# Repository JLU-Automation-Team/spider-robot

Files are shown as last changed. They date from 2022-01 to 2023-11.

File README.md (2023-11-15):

# 基于树莓派的六足机器人方案设计
## 工程内容说明
### hardware为项目相关硬件设计

 * 机械结构为六足机器人的3d建模工程，包括本体和云台<br>
 *  遥控器在ESP32最小开发板上集成了MPU6050和OLED接口并设计了使能引脚，可以选择是否收发外设数据
<br>文件包括PCB的立创EDA文件、Altium文件与3d模型<br>
### code文件夹内为使用到的各种代码

 * 包括pc控制的上位机和图传程序及其服务器程序、体感遥控器的驱动程序和树莓派部分执行程序
 * 遥控器代码和说明来自stratosphericus(Github)
### resource文件夹为项目相关的资料

 * 包括舵机控制板的串口控制指令说明以及运动控制理论及相关资料
 * 详细运控资料来自Panzer-Crow(Github)整理
### software为使用到的软件内容

 * 舵机控制板的图形化编程上位机以及可能使用到的串口驱动
## 简单预览

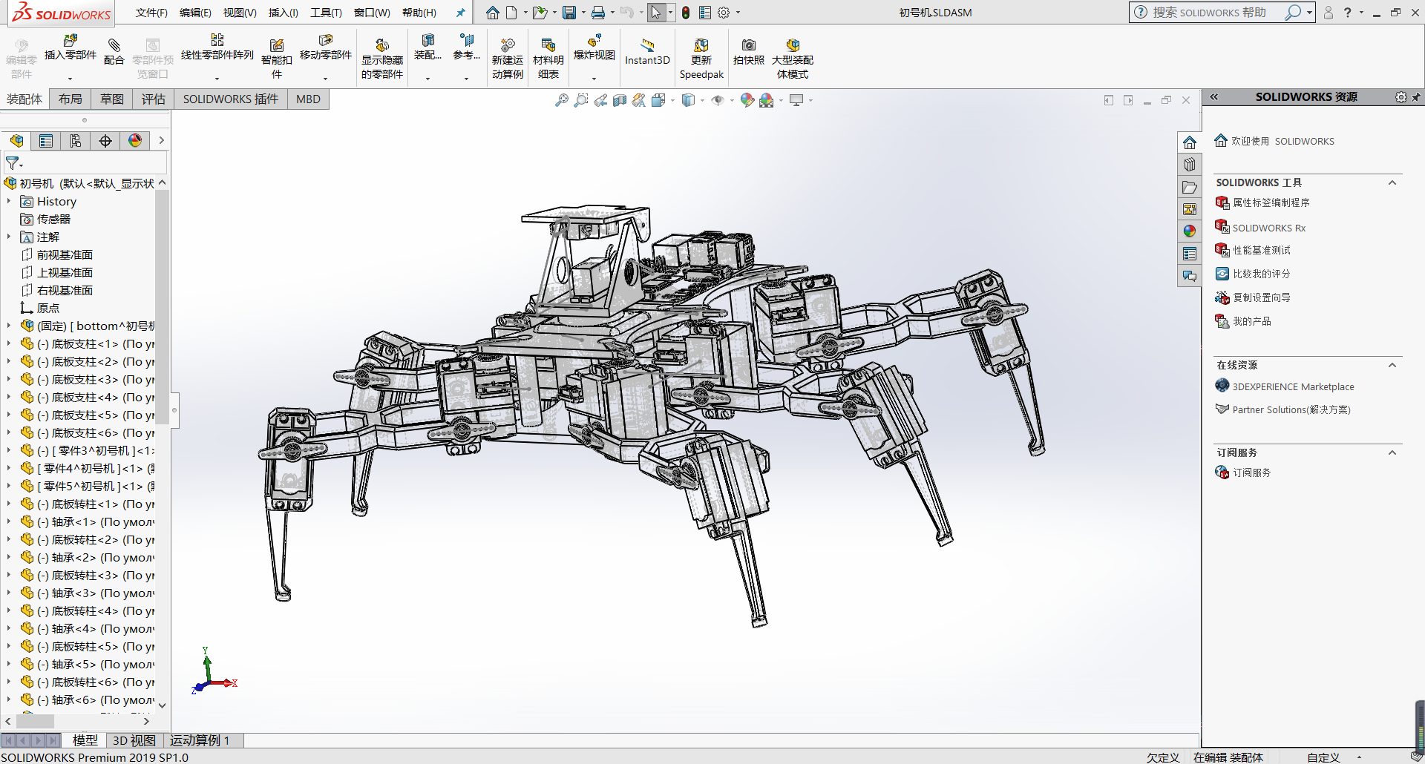
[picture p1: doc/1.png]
<br>
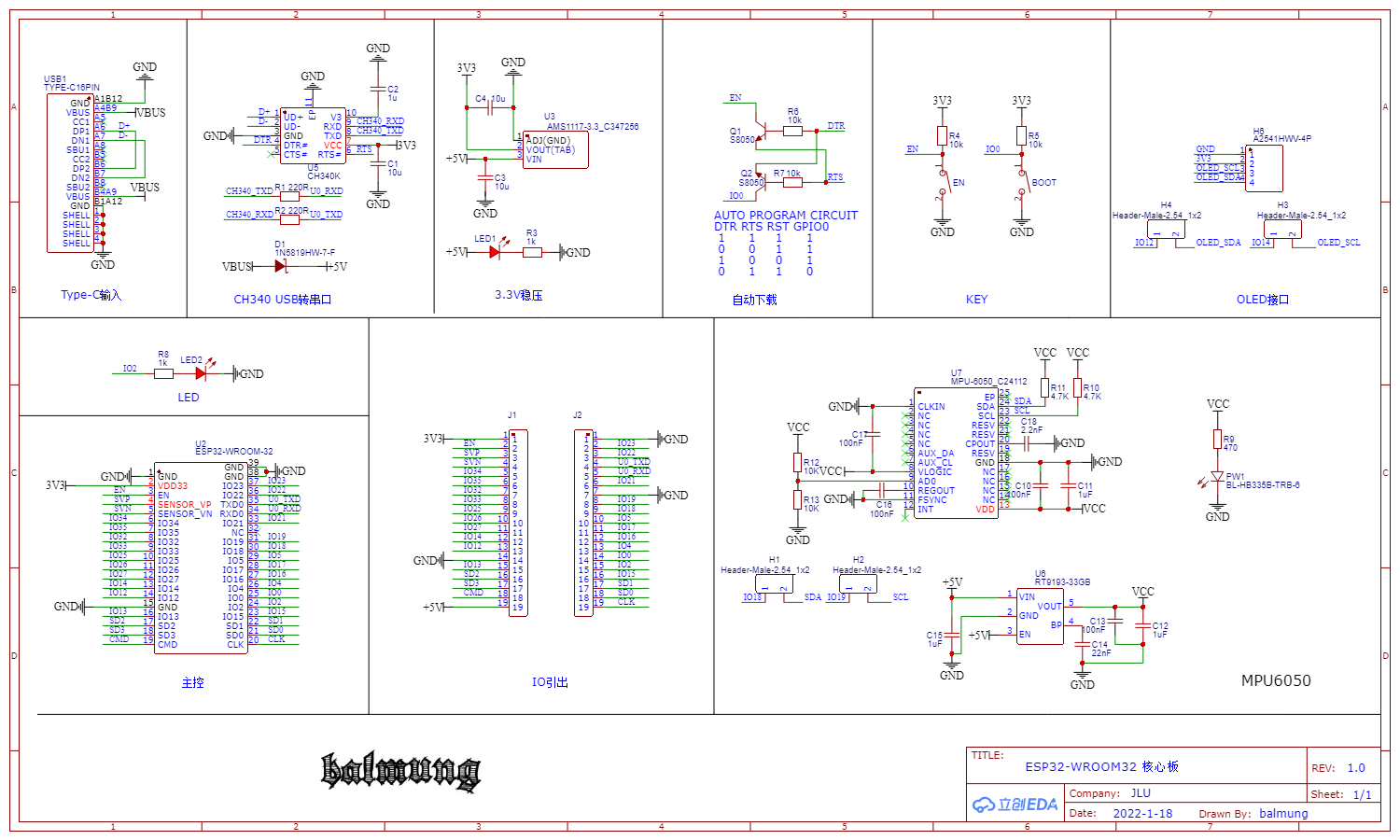
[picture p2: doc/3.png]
<br>
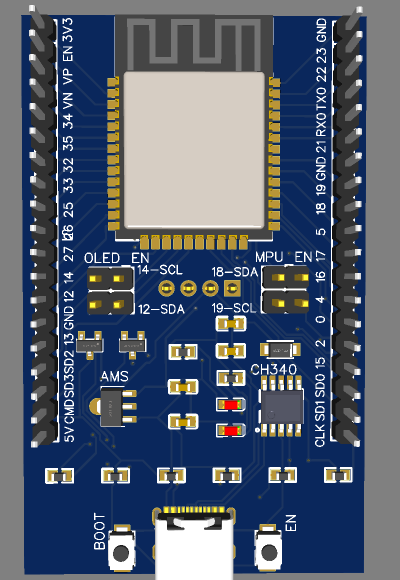
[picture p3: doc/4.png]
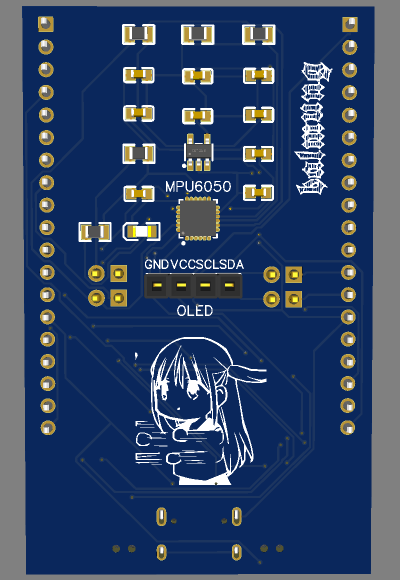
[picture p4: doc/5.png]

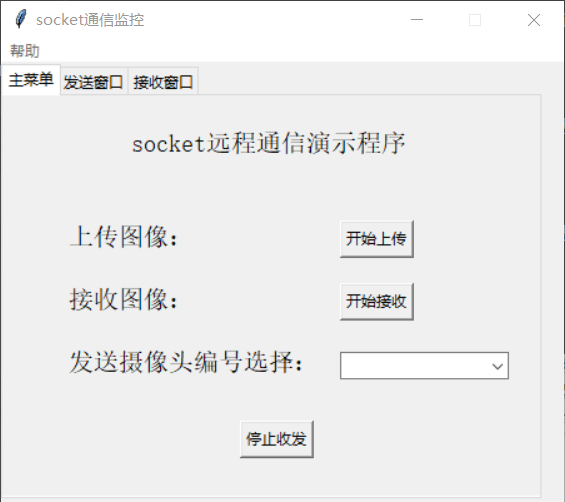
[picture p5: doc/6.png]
!<br>

## 参考与致谢

> 本说明来自balmung08(Github)<br>
> 此项目在设计中参考了https://grabcad.com/library/spider-robot-v2-0-mg995-servo-quadruped-on-stm32f103-1
感谢这帮俄国佬<br>
另外，立创EDA永远的神，我认为大家都应该试一试.jpg

>因为马上就要考研了，我们没有时间将设计做成实物，但是在设计过程中仍旧有很大收获<br>
感谢愿意陪着我一起抽风做这玩意的两位队友: BH3GEI,Panzer-Crow

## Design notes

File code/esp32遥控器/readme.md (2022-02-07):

# 基于esp32的体感手势遥控器
## 程序基本思路
### mpu6050数据处理
 * 从水平静置调零后的传感器获取三轴线加速度数据和三轴角加速度数据
 * 利用三轴线加速度数据和当地重力加速度计算出左右前后相对水平面的倾角
 * 利用z轴角速度计得到水平旋转角速度
 * 根据传感器数值分级输出移动指令和转向指令

### oled屏幕显示
 * 前两行内容分别是指令信息、局域网ip地址

### webserver的简单实现
 * 定义好响应头之后进入死循环开始监听，响应来自客户端的GET请求
 * 返回内容是一个与oled屏幕第一行内容相同的字符串

## 食用方法
 * 接好供电，连好引脚（mpu和oled都是3v3供电；mpu的接gpio5, sda接gpio4；oled的sda接gpio13, scl接gpio14）
 * 晃动遥控器
 * 树莓派的运控程序向esp32的ip地址(80端口)发送GET请求，得到遥控器产生的指令(同时指令会在oled上显示)

## 可能存在的问题
 * oled与mpu6050直接并联在esp32的3v3和gnd管脚之间可能导致mpu6050烧毁

## 参考来源：

>mpu6050的驱动来源: https://github.com/macalencar/micropython-mpu6050/blob/main/mpu6050.py

>ssd1306 oled屏幕的驱动来源: https://github.com/adafruit/micropython-adafruit-ssd1306/blob/master/ssd1306.py

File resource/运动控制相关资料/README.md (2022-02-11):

* 本部分说明文档涉及大量公式，Github无法正常加载，请下载项目后使用markdown阅读器打开

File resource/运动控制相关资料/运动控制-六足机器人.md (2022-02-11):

# 运动控制方案
## 实例项目——六足机器人（Spider Robot）
 
------
### 写在方案前的话
**本方案根据<font color=#dd0000>严密数学建模</font>和<font color=#dd0000>工程快速实现</font>的方面不同准备有两套不同操作方案，希望了解严密数学建模的朋友请耐心看完全文，有迫切工程实现需求的朋友可在看完第1点简介后直接，从第五点开始查看，需要说明的是，两种方式仅在学习的时间成本上会有明显不同，在具体项目实现的时间上会因为个人的熟练程度的因素不一定会展现出差异**

### 目录
> * 1.本项目六足机器人简介
> * 2.常用机械臂模型——DH模型的基本思想
> * 3.DH模型提出的数学原理
> * 4.本项目六足机器人的单足（单机械臂）建模方式
> * 5.本项目六足机器人的多足（多机械臂）运动逻辑——步态规划
> * 6.项目工程实现方式及相关软件
> * 7.注意要点

------
### 1.本项目六足机器人简介
项目SolidWorks预览图
 **项目SolidWorks预览图**

 在运动控制方面，本项目六足机器人使用树莓派作为主控板，使用24路舵机控制板作为18个舵机（6足：每足3个）的运动控制，并且使用降压芯片将7.4V电池电压降为6.2V电压给舵机控制板供电；在舵机选用上，使用最为常见的MG995舵机，并使用Lobot Servo Control软件对18个舵机同一管理。

------
### 2.常用机械臂模型——DH模型的基本思想
DH模型，即Denavit-Hartenberg模型，是连杆结构常用的建模方式，可以运用于任何机器人的运动构型，特别是在多自由度机械臂上运用广泛。

在DH模型中，一个多自由度的连杆结构（或机械臂）是由一个个<font color=#dd0000>关节</font>和<font color=#dd0000>连杆</font>组成的，其中每个关节只有一个自由度，根据运动形式的不同，关节可分为滑动关节（P关节）和转动关节（R关节）。

这里我们引入两个概念：<font color=#dddd00>正运动学</font>和<font color=#dddd00>逆运动学</font>，<font color=#dddd00>正运动学</font>即是指已知各个关节的运动参数，求末端执行器相对于参考坐标的位姿,<font color=#dddd00>逆运动学</font>是指根据已给定的满足工作要求的末端执行器相对于末端执行器的位置和姿态，求各个关节的运动参数。以正运动学为背景的话，DH模型通过限制**原点位置**和**X轴方向**，可以人为的减少2个参数，所以只需要4个参数就可以表达关节之间原本6参数才能表达的坐标变换。

------
### 3.DH模型提出的数学原理
* DH模型的四个核心参数
  
> * 连杆长度（link length）：两个关节之间公共法线长度，以符号a<sub>i−1</sub> 表示,
> 【对于关节点O<sub>i-1</sub> 和 O<sub>i</sub> 】
> * 连杆扭转（link twist）： 一个关节的轴相对于另一个关节的轴绕他们公共法线的旋转角度,以符号α<sub>i−1</sub>表示 
> 【对于关节点O<sub>i-1</sub> 和 O<sub>i</sub> 】
> * 连杆偏移（link offset）：一个关节余下一个关节的公共法线和这个关节与它上一个关节公共法线沿这个关节轴的距离，以符号d<sub>i </sub>表示
> 【对于轴X<sub>i-1</sub> 和 X<sub>i</sub> 】
> * 关节转角（joint angel）：一个关节与下一个关节公共法线和它与上一个关节的公共法线绕这个关节的转角，以符号θ<sub>i</sub> 表示
> 【对于轴X<sub>i-1</sub> 和 X<sub>i</sub> 】

* 模型图像

------
<center>
    
</center>

<center>

**任意一个拥有三个关节和两根连杆的机械结构【真实视图】**

</center>

<center class="half">
    
</center>

$~~~~~~~~~~~~~~~~~$**抽象数学模型视图【正视图】**$~~~~~~~~~~~~~~~~~~~~~~~~~~~~~~~~~~~~~~~~~~~~~$**抽象数学模型视图【左视图】**

<center class="half">
    
</center>

$~~~~~~~~~~~~~~~~~$**抽象数学模型视图【正视图】**  $~~~~~~~~~~~~~~~~~$$~~~~~~~~~~~~~~~~~$$~~~~~~~~~~~$**抽象数学模型视图【正视图】**

$~~~~~~~~~~~~~~~~~$**（去掉1，3号关节转轴）**$~~~~~~~~~~~~~~~~~$$~~~~~~~~~~~~~~~~~$$~~~~~~~~~~~~~~~~~$**（去掉1，3号关节转轴）**

------
* 矩阵计算——涉及空间坐标变换

$$
空间坐标变换
\left\{ 
\begin{matrix}
二维图形变换【旧坐标(x,y)——>新坐标(X,Y)】
\left\{ 
\begin{matrix}
平移 \\
缩放（此处不考虑）\\
旋转\\
\end{matrix}
\right. \\
三维图形变换【旧坐标(x,y,z)——>新坐标(X,Y,Z)】
\left\{ 
\begin{matrix}
平移 \\
缩放（此处不考虑）\\
旋转\\
\end{matrix}
\right.\\
\end{matrix}
\right.
$$

> 为方便计算，在这里我们引入齐次坐标，齐次坐标是一种标记方式
>* 对于二维坐标点来说，原来为（x,y）的坐标表示为（x,y,1）
>* 对于二维坐标点来说，原来为（x,y,z）的坐标表示为（x,y,z,1）
>* 齐次坐标可以在空间变换计算中区分向量和坐标，如二维的：
$$
\left\{ 
\begin{matrix}
向量：（x,y,0）\\
坐标： (x,y,1) \\
\end{matrix}
\right.
$$

$$
二维平移变换【引入齐次坐标后，等待变换的点：（x,y,1）】
\left\{ 
\begin{matrix}
变换公式
\left\{ 
\begin{matrix}
X=x+\delta x \\
Y=y+\delta y\\
\end{matrix}
\right.\\
变换矩阵:\left[
 \begin{matrix}
   1 & 0 & \delta x \\
   0 & 1 & \delta y \\
   0 & 0 & 1 
  \end{matrix}
  \right] *(x,y,1)=[x+\delta x,y+\delta y,1] \\
\end{matrix}
\right.
$$

$$
二维旋转变换【引入齐次坐标后，等待变换的点：（x,y,1）】
\left\{ 
\begin{matrix}
变换公式
\left\{ 
\begin{matrix}
X=x*cos\theta -y*sin\theta \\
Y=y*cos\theta +x*sin\theta \\
\end{matrix}
\right.\\
变换矩阵:\left[
 \begin{matrix}
   cos\theta & -sin\theta & 0 \\
   sin\theta & cos\theta & 0 \\
   0 & 0 & 1 
  \end{matrix}
  \right] *(x,y,1)=[x*cos\theta -y*sin\theta,y*cos\theta +x*sin\theta,1] \\
\end{matrix}
\right.
$$

> 推得各个变换矩阵（左乘坐标变换）：
> (证明为三角变换内容，此处省略)
> 二维平移变换矩阵：
$$
\left[
 \begin{matrix}
   1 & 0 & \delta x \\
   0 & 1 & \delta y \\
   0 & 0 & 1 
  \end{matrix}
  \right]
$$
> 二维旋转变换矩阵：
$$
\left[
 \begin{matrix}
   cos\theta & -sin\theta & 0 \\
   sin\theta & cos\theta & 0 \\
   0 & 0 & 1 
  \end{matrix}
  \right] 
$$

> 三维同理：
> 三维维平移变换矩阵：
$$
\left[
 \begin{matrix}
   1 & 0 & 0 &\delta x  \\
   0 & 1 & 0 & \delta y \\
   0 & 0 & 1 & \delta z \\
   0 & 0 & 0 &    1     \\
  \end{matrix}
  \right]
$$
> 三维旋转变换矩阵：
> 若绕X轴:
> $$
\left[
 \begin{matrix}
   cos\theta & -sin\theta &  0  &  0\\
   sin\theta & cos\theta  &  0  &  0\\
   0         &     0      &  1  &  0\\
   0         &     0      &  0  &  1
  \end{matrix}
  \right] 
$$
> 若绕Y轴:
> $$
\left[
 \begin{matrix}
   cos\theta & 0 &  -sin\theta  &  0\\
   0 &  1 &  0  &  0\\
   sin\theta   &     0     &  cos\theta  &  0\\
   0         &     0      &  0  &  1
  \end{matrix}
  \right] 
$$
> 若绕Z轴:
> $$
\left[
 \begin{matrix}
   1 & 0 &  0  &  0\\
   0 & cos\theta & -sin\theta &  0\\
   0         &     sin\theta & cos\theta  & 0\\
   0         &     0      &  0  &  1
  \end{matrix}
  \right] 
$$

对于我们研究的六足机器人项目（三维结构），根据每两个关节之间的的旋转变换矩阵（R<sub>x</sub>或R<sub>y</sub>或R<sub>z</sub>）和平移变换矩阵（T）相乘再与原坐标左乘，就可得到下一个点的坐标，递推直到获得末端足姿坐标。**这样一来，我们便实现了由已知各个关节的运动参数，求得末端执行器相对于参考坐标的位姿【由于推导比较麻烦，为回避计算量，下一板块会直接给出两关节间化简后的的变换矩阵，在填好DH表格后，可直接由数据计算坐标】**

------
### 4.本项目六足机器人的单足（单机械臂）建模方式——正运动学与逆运动学

-----

####正运动学分析

#### ①物理结构抽象
  
<center>

项目单臂机械结构示例图

 **项目单臂机械结构示例图**

</center>
#### ②数学抽象 

<center>

项目数学模型抽象示例图
 **项目数学模型抽象示例图**

</center>

* 对于一个机械臂的每一个关节 指定一个本地参考坐标系，即指定一个<font color=#dd0000>X轴</font>和一个<font color=#dd0000>Z轴</font>：其中Z轴以右手螺旋定则按照旋转方向规定正方向，X轴分两种情况：若两关节轴不平行或相交，用最短公垂线为X轴；平行，用无数条相等的公垂线中任选一条为X轴

#### ③明确参数，填写DH表格

| i | a<sub>i−1  | α<sub>i−1 |d<sub>i |θ<sub>i  |
| ---| :-----:  | :----:  |:----:|:----:|
| 1 | | | | |
| 2 | | | | |
| 3 | | | | |

#### ④将表格数据代入两关节间化简后转换矩阵公式
> $$
T_{i-1}=
 \left[
 \begin{matrix}
   cos\theta _i & -sin\theta _i & 0 & \ a_{i-1} \\
   sin\theta _icos\alpha _{i-1} & cos\theta _icos\alpha _{i-1} & -sin\alpha _{i-1}&-sin\alpha _{i-1}d_i\\
  sin\alpha _{i-1}sin\theta _i & cos\theta _isin\alpha _{i-1} & cos\alpha _{i-1} &cos\alpha _{i-1}d_i\\
   0 & 0 & 0 &1\\
  \end{matrix}
  \right] 
$$ 

#### ⑤将得到的变换矩阵T<sub>0</sub>、T<sub>1</sub>、T<sub>2</sub>与原始坐标（0,0,0,1）相乘得到足端位姿坐标：
> （X,Y,Z,1）=T<sub>2</sub>*T<sub>1</sub>*T<sub>0</sub> *(0,0,0,1)

------
#### 逆运动学分析
不同与正运动学清晰的矩阵计算，逆运动学的处理显得更为复杂，逆运动学的求解一般有**数值解计算**和**封闭形式解决方案**。由于本项目并非多自由度的工业机械臂一类的应用场景，可以通过之后描述的方案二使用**人为试错**的方式获得舵机转角值，在此不对逆运动学解做具体阐述，只是保证知识完整性做相关说明。
在实际运用中，我们并不是通过已知的各舵机转角来获得末端位姿。相反，我们需要在已知目标末端位姿（x,y,z,1）的前提下，获得每个舵机的转角以输入程序使得舵机带动机械臂末端到达目标位置。可以说，逆运动学在实际中的运用要多于正运动学。

具体的求解方法可参考CSDN博客：
网址链接：[尘埃落定123——《逆运动学》]([C:2.png](https://blog.csdn.net/u011280600/article/details/80452022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))

------
### 5.本项目六足机器人的多足（多机械臂）运动逻辑——步态规划
为方便本栏的说明，我们需要先引入一些概念

>* 步态：指机器人的每条腿按一定顺序和轨迹的运动过程
>* 步态周期：多足机器人完成一个步态的时间，所有腿轮番完成“提起——摆动——放下”所花费的时间
>* 占地系数：每条腿接触地面的时间和整个步态周期的比值
> $~~~~~~~~~~~~~~~$【当占地系数小于0.5】六足机器人任何瞬间只有不到三条腿支撑地面，称为**跳跃步态**
> $~~~~~~~~~~~~~~~$【当占地系数等于0.5】机器人用两组腿交替摆动，称为小跑**跳跃步态**
> $~~~~~~~~~~~~~~~$【当占地系数大于0.5】机器人轮番有三条腿以上支撑地面，称为爬行**跳跃步态**
>* 步幅：机器人重心在一个步态周期的平移

为方便后续步态说明，我们引入一般情况下的六足机器人简图如图所示，有前足1、2，中足3、4，后足5、6.
<center>
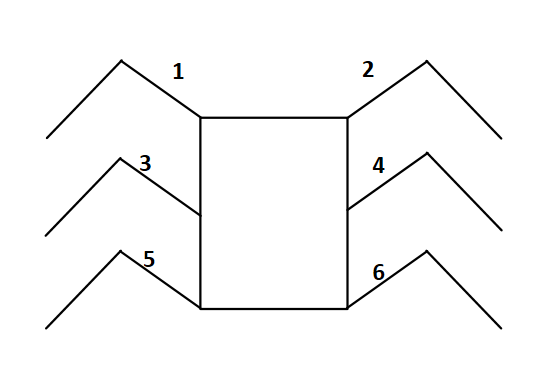
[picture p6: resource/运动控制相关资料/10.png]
    
</center>

<center>

**引入一般情况下的六足机器人简图**

</center>

**常见的步态**
>* 三角步态：即是将6条足分为两组，【1，4，5】为A组，【2，3，6】为B组，通过“在A组迈腿行走时，B组当作三角形稳定支架；B组迈腿行走时，A组当三角形稳定支架，来进行移动”，**其行进的方式是直线运动+原地自转**。三角步态是自然界“六足纲”昆虫最常用的方式。三角步态的优点是操控逻辑简单，运行平稳，故障率低；缺点是只适用于平整、路况良好地面，对于复杂山地或多石泥泞地形适应性不强。
>* 跟导步态：也即是使中足（3，4）和后组（5，6）跟导两对前足（1，2），步态行走形式只由前两足**落点**决定。由于会根据每次前足落点的不同调节步态，而不是像三角步态一样固定行进，因此对于复杂地形的适应能力也更强；且由于只用关注两个前足的的落点作为输入就可以给出所有其余足的控制，因此其控制逻辑也不难。
>* 交替步态：此步态以单独的一条足为基本单元，控制逻辑是当一条足的相邻两足均已经触地，该足才被允许抬起前进，同样在其落地时，会给相邻两组发出已触地的信号，不同的足顺次运动。可分为平整地形和复杂地形来讨论，在平整地形上，其表现效果与三角步态与三角步态相似；对于复杂地形，步态的运动方式是不可预测的。

**在本项目中我们选择我们选择最为常用的三角步态，即是六足分为两组轮流充当支撑组和移动组**

------
### 6.项目工程实现方式及相关软件
本项目使用Lobot Servo Control对18个舵机以<font color=#dd0000>动作组</font>的形式控制。简单来说，我们把舵机的要完成的复杂操作称为动作组，而将动作组拆分则可以得到<font color=#dddd00>单一动作</font>。所谓单一动作，指的是**当舵机控制板发出一个操作命令后，所有18个舵机所处的旋转稳定后的空间状态**。

举个例子，如我想先<font color=#dd0000>使1，2足向前伸，3，4号足不动，然后5，6号足向后伸</font>,而这就称之为一个<font color=#dd0000>运动组</font>，因为有时间的先后关系，所以这个运动组包含，<font color=#dddd00>使1，2足向前伸</font>，<font color=#dddd00>3，4号足不动</font>，<font color=#dddd00>5，6号足向后伸</font>这3个<font color=#dddd00>单一动作</font>，分别受3条指令控制。我们要实现这个动作组需要先设置舵机位置使1，2号机械臂的6个舵机的目标值，使其伸直，这是第一条指令；在第二条指令中，我们完全保持现有的舵机状态，即所有舵机的目标值不变；第三条指令中，我们设置舵机位置使5，6号机械臂的6个舵机的目标值使5，6号机械臂后伸，这样就完成一个动作组。

而通过对于不同动作组的组合，我们便可以使六足机器人做出不同的行为。这就好比人走路有许多重复性的迈步，我们细分的话，将走路这一行为由不断重复地**迈左脚，然后迈右脚**的这一动作组组成，而在这个动作组当中包含具有先后顺序的**迈左脚**和**迈右脚**这两个动作。而本项目六足机器人的运动逻辑正是基于这一思路提出来的。

以下是两种不同的方案，其中方案一因为在前面的介绍中做了较为具体的阐述，在此就不过多说明。

* 方案一
  通过矩阵计算，可以达到的效果是,在获得需要到达的末端位姿坐标后，可以通过计算获得一个“最近”的接近末端目标点的3个多级旋转角度的数值解，原理上即使之前的逆运动学原理。

* 方案二
  上述的操作方式固然在数学上更具有严密性，但是我们知道，虽然我们能保证矩阵计算的准确性，但在实际过程中，测量误差、机械精度等问题是无法避免的，我们需要做细微调整，使运动效果更好，那么既然运动效果可以实时调整，且调节本身也是可视化的，我们可不可以直接“目测效果”调试呢？答案是可以的。
Lobot Servo Control操作界面
通过对六足机器人三角步态拆分，分为直线运动和原地自转，得到不同运动组，在分别编写（记录舵机位置）不同单一运动，我们同样可以使六足机器人顺利行走。

**需要指出的时，上述的方案二是一种“力大砖飞”的方式，对于精度要求不高，且试错成本较低甚至没有试错成本的场合是适用的，如本项目当中，其本质是以人脑作为反馈调节机构，对错误进行修正，是“摸着石头过河”，不建议过于依赖，且之所以能够选择方案二是由于本项目的立项背景是应用于平整路面，也基于此选择了<font color=#dd0000> 三角步态</font>  ，所以对于每一次步幅的增加，其控制代码没有差异；而对于精度要求高，试错成本大，需要其他步态模式以应对更加复杂地形的场景时，或难以使人直接对执行效果进行评估或修正的系统时，应对机械臂进行数学建模，通过正运动学和逆运动学的理论，为其建立准确的理论模型再进行工程实现。**

------
### 7.注意要点
* 注意在实际代码编写中，各个舵机的中值可能会有不同，建议先进行统一调试

<br><br>

------
> 本笔记由Panzer-Crow(Github)整理
> 鸣谢本项目中的两位队友：stratosphericus(Github),balmung(Github)
------

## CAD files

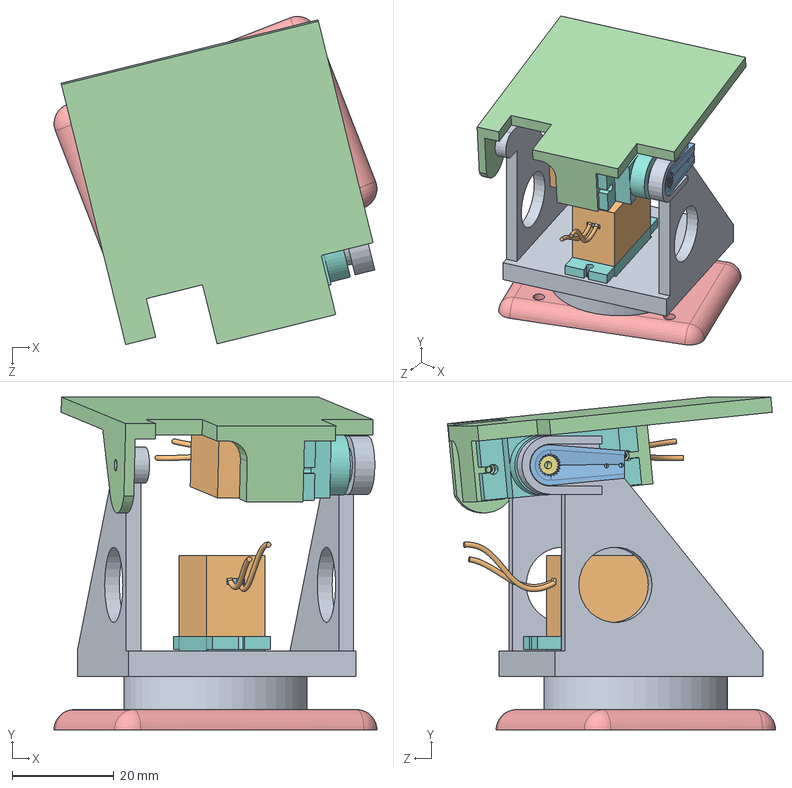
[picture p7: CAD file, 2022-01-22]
hardware/云台/云台2号机 .SLDASM
63.4 x 65.3 x 64.4 mm
云台2
lower cover^servo motor assembley(2)_servo motor assembley x 2
motor^servo motor assembley(2)_servo motor assembley x 2
feedback potentiometer^servo motor assembley(2)_servo motor assembley x 2
复件 (2) ^servo motor assembley(2)_servo motor assembley x 2
复件 (3) ^servo motor assembley(2)_servo motor assembley x 2
复件 (4) ^servo motor assembley(2)_servo motor assembley x 2
upper cover^servo motor assembley(2)_servo motor assembley x 2
复件 (6) ^servo motor assembley(2)_servo motor assembley x 2
复件 (7) ^servo motor assembley(2)_servo motor assembley x 2
舵机配件1 x 2
云台3
云台1

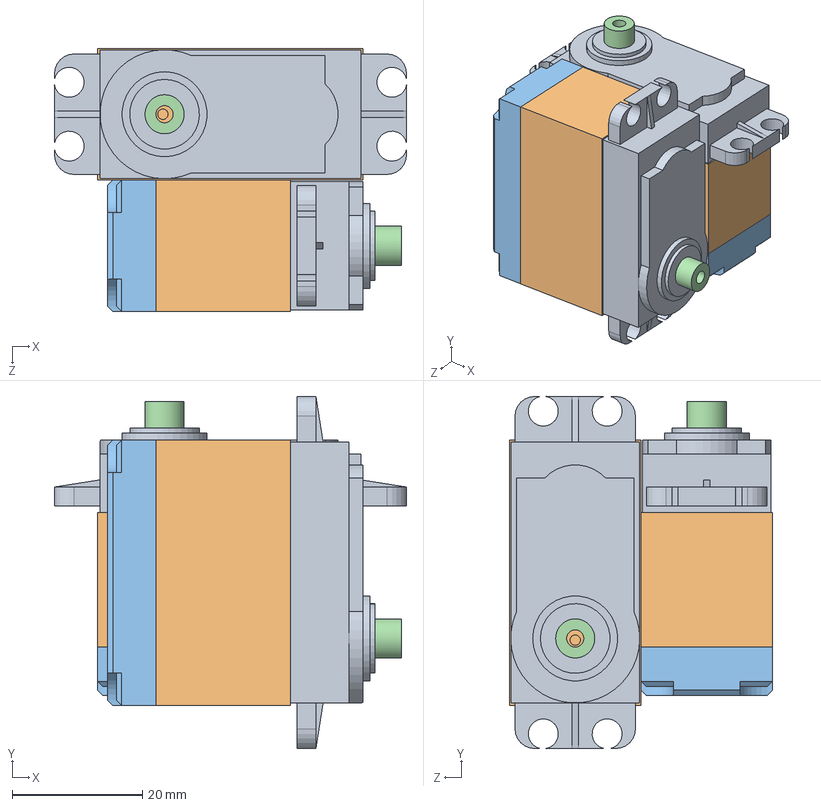
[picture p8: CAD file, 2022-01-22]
hardware/机械结构/装配体1.SLDASM
54.0 x 54.0 x 40.4 mm
MG995前板 x 2
MG995中板 x 2
MG995后板 x 2
MG995齿轮 x 2

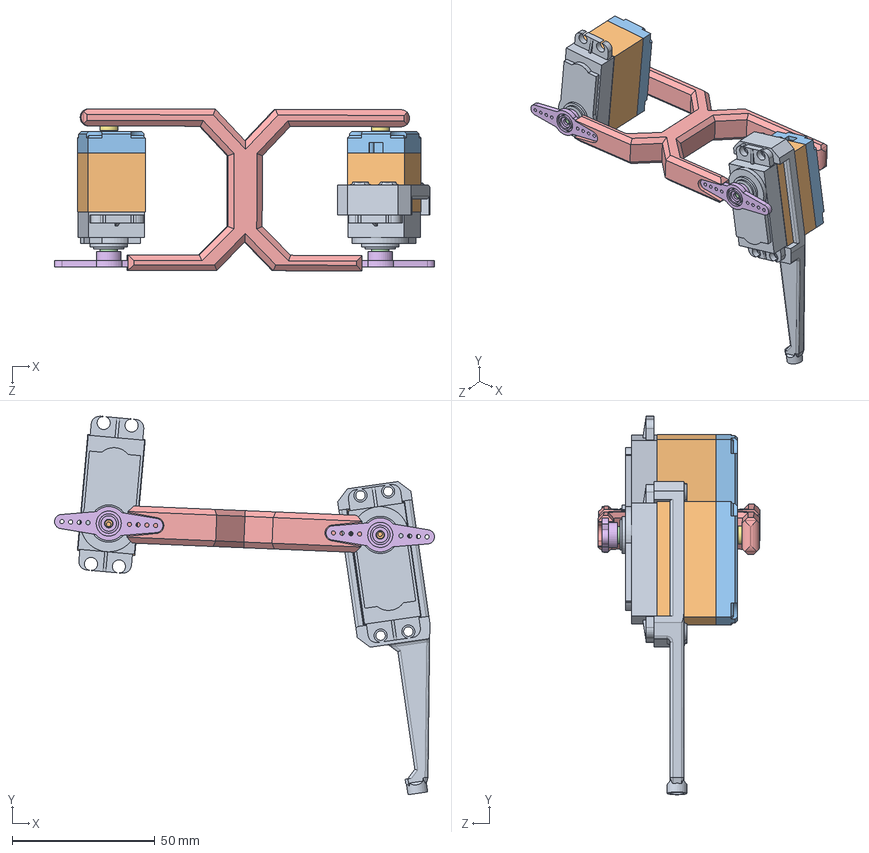
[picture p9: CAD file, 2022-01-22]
hardware/机械结构/腿2.SLDASM
133.0 x 132.5 x 56.8 mm
MG995前板 x 2
MG995中板 x 2
MG995后板 x 2
MG995齿轮 x 2
腿上部
舵机配件 x 2
腿部转柱 x 2
轴承 x 2
腿2下部

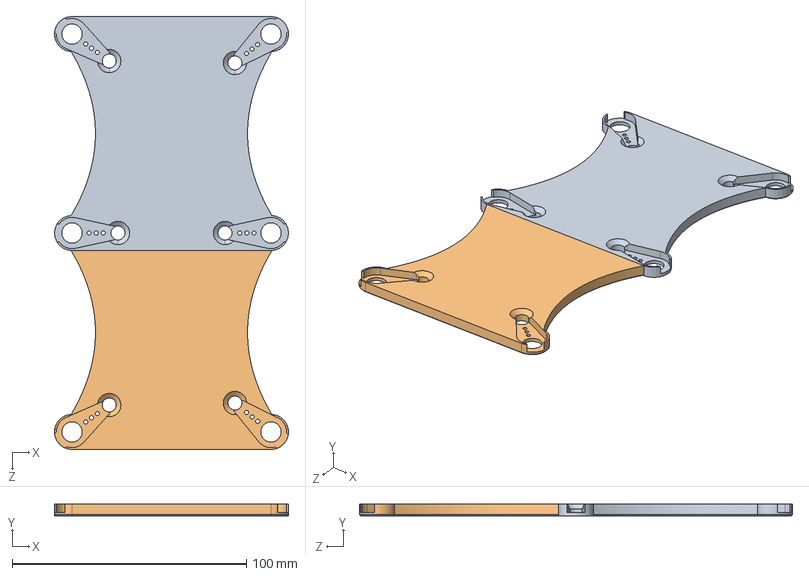
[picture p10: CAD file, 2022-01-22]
hardware/机械结构/top(3).SLDASM
100.0 x 5.00 x 185.0 mm
Основание нижнее^_top(3)_top(3)
_private_var_mobile_Containers_Data_Application_327FD876-EF9E-4CCE-9D75-9D16AF0753A7_tmp_B33AE067-E3AF-4F21-8502-7502B160869B.tmp(2)^top(3)_top(3)

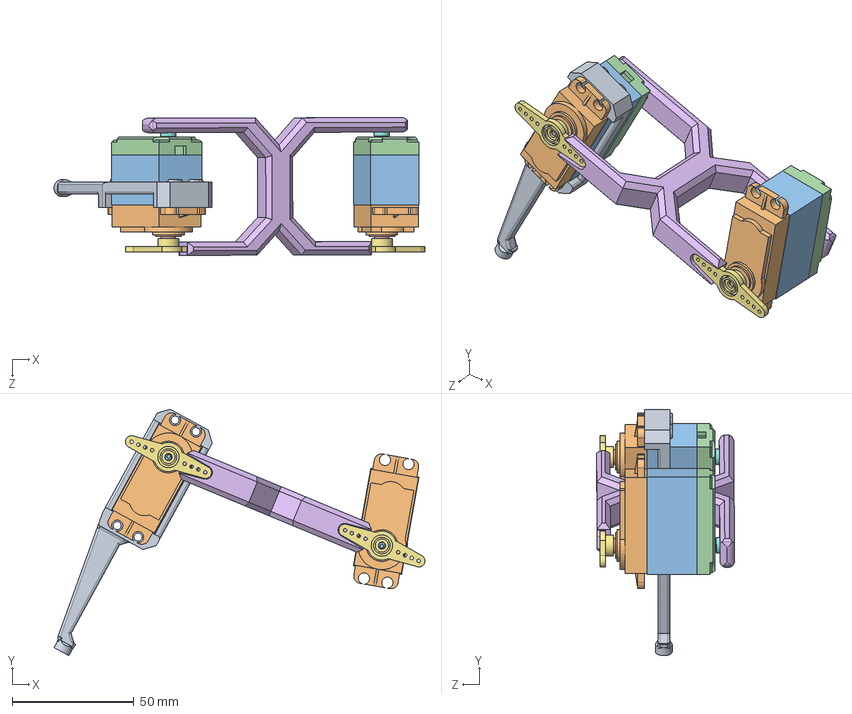
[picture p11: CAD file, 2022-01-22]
hardware/机械结构/腿1.SLDASM
152.7 x 101.4 x 56.8 mm
腿1下部
MG995前板 x 2
MG995中板 x 2
MG995后板 x 2
MG995齿轮 x 2
腿上部
舵机配件 x 2
腿部转柱 x 2
轴承 x 2

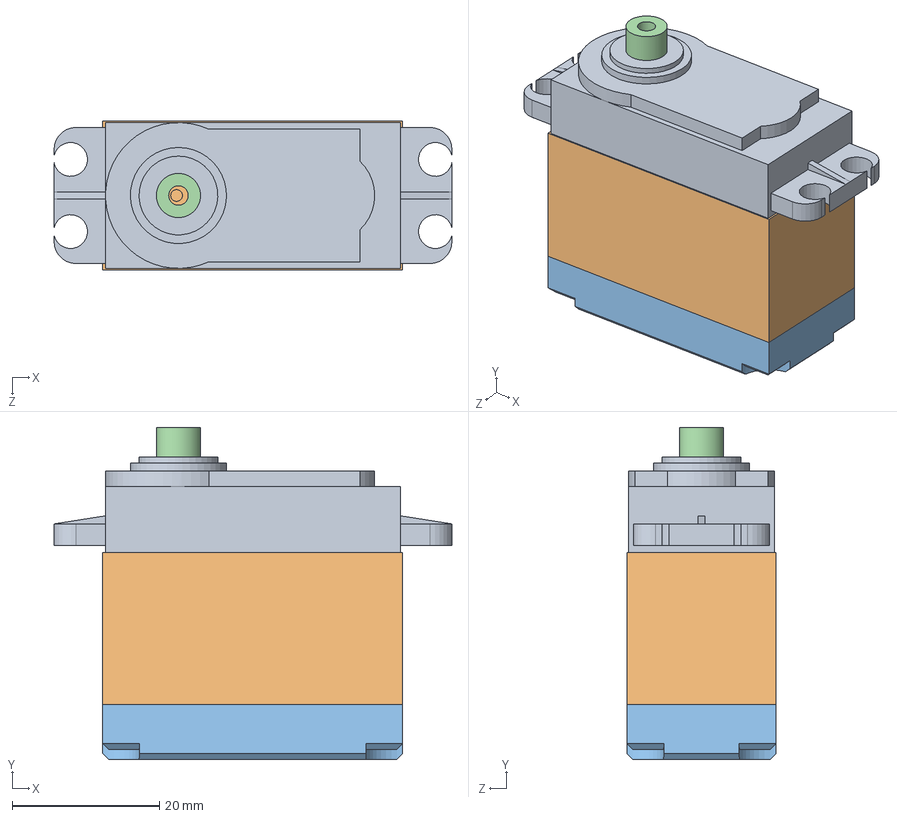
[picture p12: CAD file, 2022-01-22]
hardware/机械结构/Servo MG955.SLDASM
54.0 x 45.1 x 20.2 mm
MG995前板
MG995中板
MG995后板
MG995齿轮

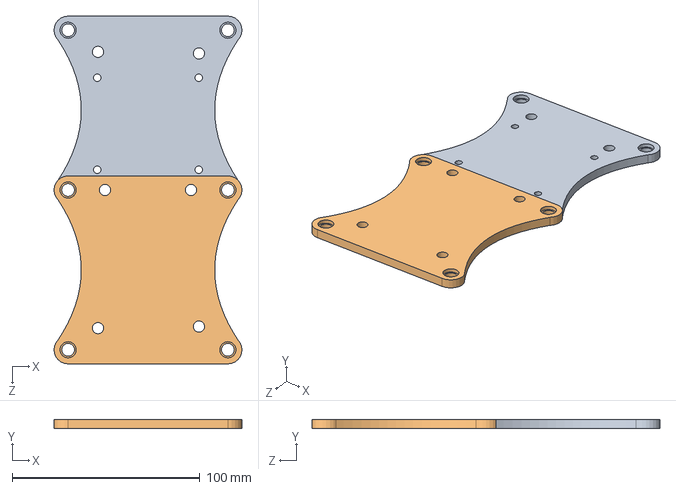
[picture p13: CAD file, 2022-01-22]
hardware/机械结构/bottom^666.SLDASM
100.0 x 5.00 x 185.0 mm
Основание нижнее.SLDPRT^bottom_666
Основание нижнее.SLDPRT-0^bottom_666

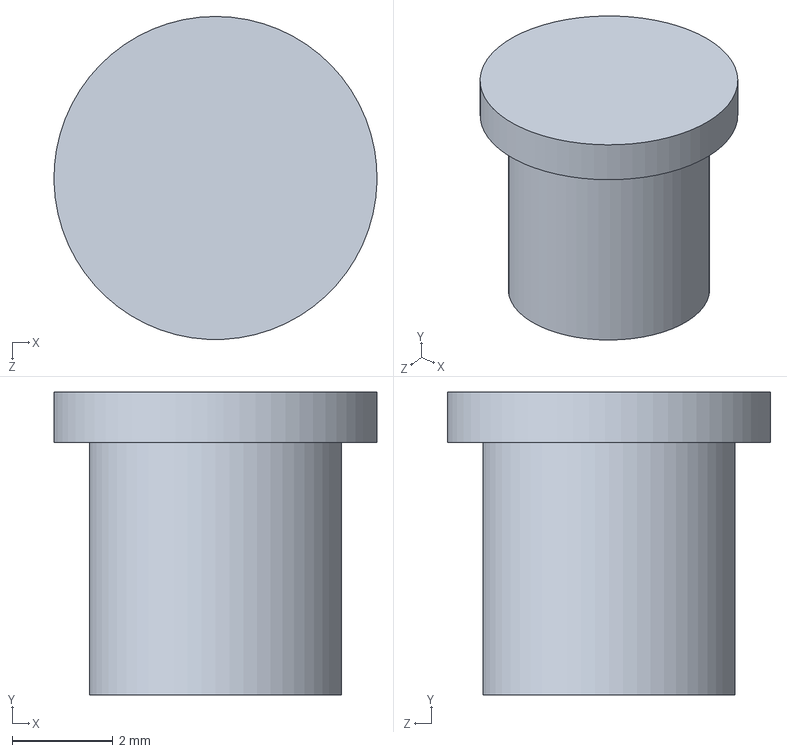
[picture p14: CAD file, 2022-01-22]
hardware/机械结构/底板转柱.SLDPRT
6.40 x 6.00 x 6.40 mm

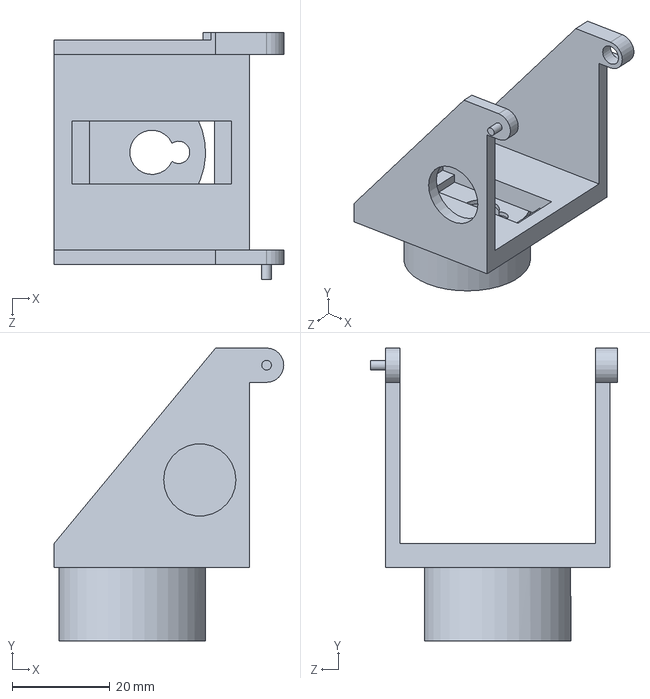
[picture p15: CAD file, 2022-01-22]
hardware/云台/云台2.SLDPRT
47.0 x 60.0 x 50.5 mm

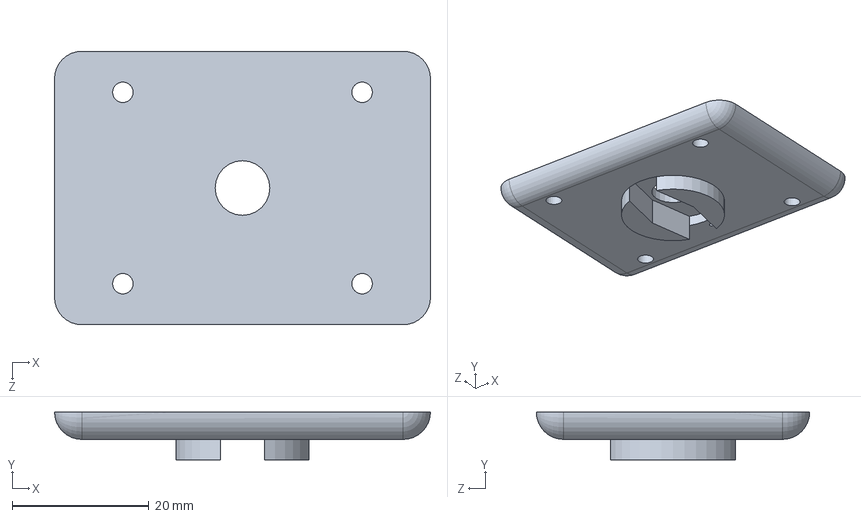
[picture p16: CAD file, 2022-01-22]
hardware/云台/云台1.SLDPRT
55.0 x 7.00 x 40.0 mm

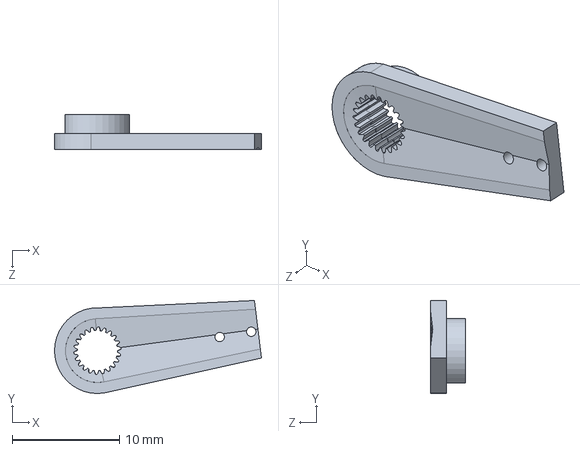
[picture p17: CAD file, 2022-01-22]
hardware/云台/舵机配件1.SLDPRT
19.3 x 8.68 x 3.30 mm

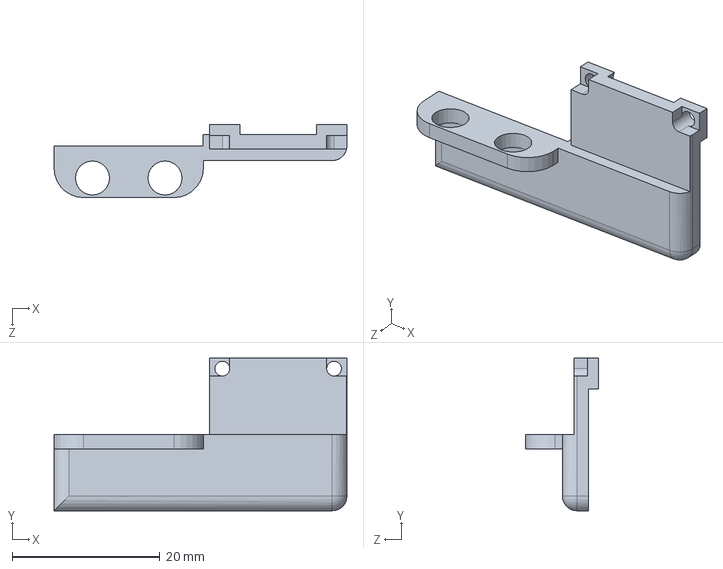
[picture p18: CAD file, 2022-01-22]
hardware/机械结构/固定件2.sldprt
39.6 x 20.6 x 9.90 mm

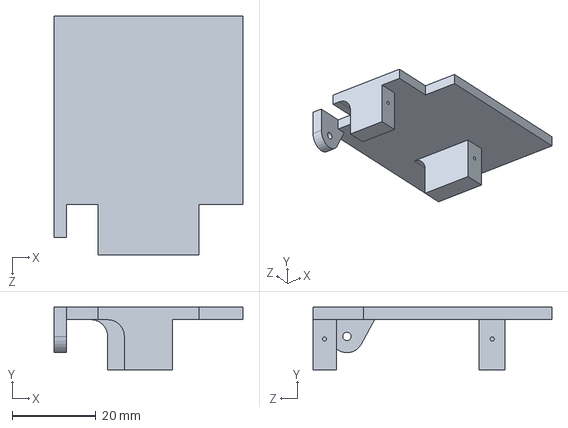
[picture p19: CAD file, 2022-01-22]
hardware/云台/云台3.SLDPRT
45.0 x 15.0 x 57.0 mm

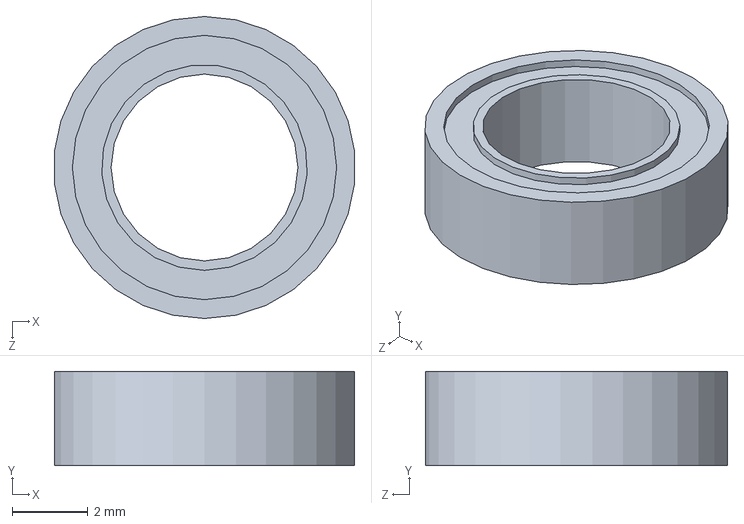
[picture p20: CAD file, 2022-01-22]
hardware/机械结构/轴承.SLDPRT
7.96 x 2.50 x 8.00 mm

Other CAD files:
hardware/机械结构/镜向固定件2.sldprt
hardware/机械结构/舵机驱动板示意图.SLDPRT
hardware/机械结构/镜向固定件1.sldprt
hardware/机械结构/腿2下部.SLDPRT
hardware/机械结构/MG995中板.SLDPRT
hardware/机械结构/MG995前板.SLDPRT
hardware/机械结构/MG995后板.SLDPRT
hardware/机械结构/MG995齿轮.SLDPRT
hardware/机械结构/固定件1.sldprt
hardware/机械结构/底板支柱.SLDPRT
hardware/机械结构/腿1下部.SLDPRT
hardware/机械结构/腿上部.SLDPRT
hardware/机械结构/腿部转柱.SLDPRT
hardware/机械结构/舵机配件.SLDPRT

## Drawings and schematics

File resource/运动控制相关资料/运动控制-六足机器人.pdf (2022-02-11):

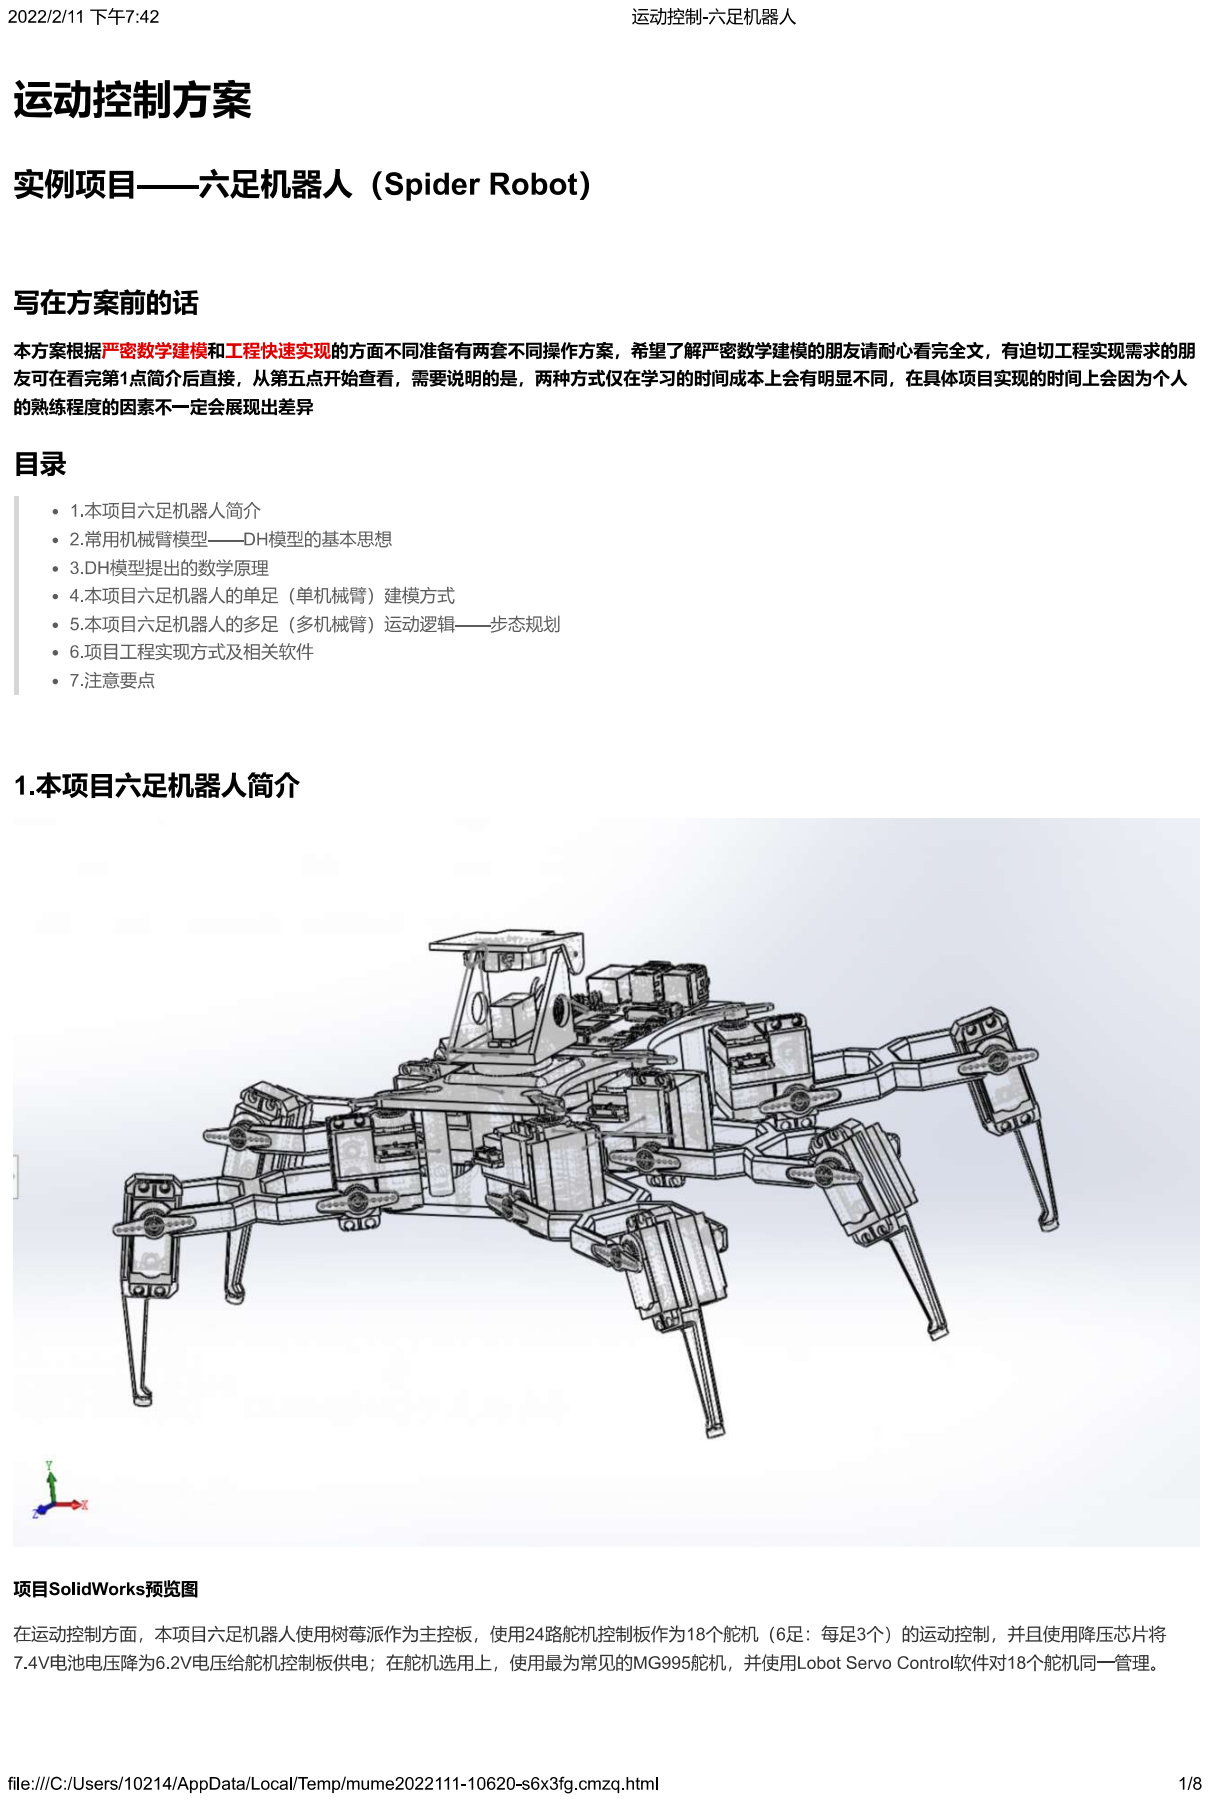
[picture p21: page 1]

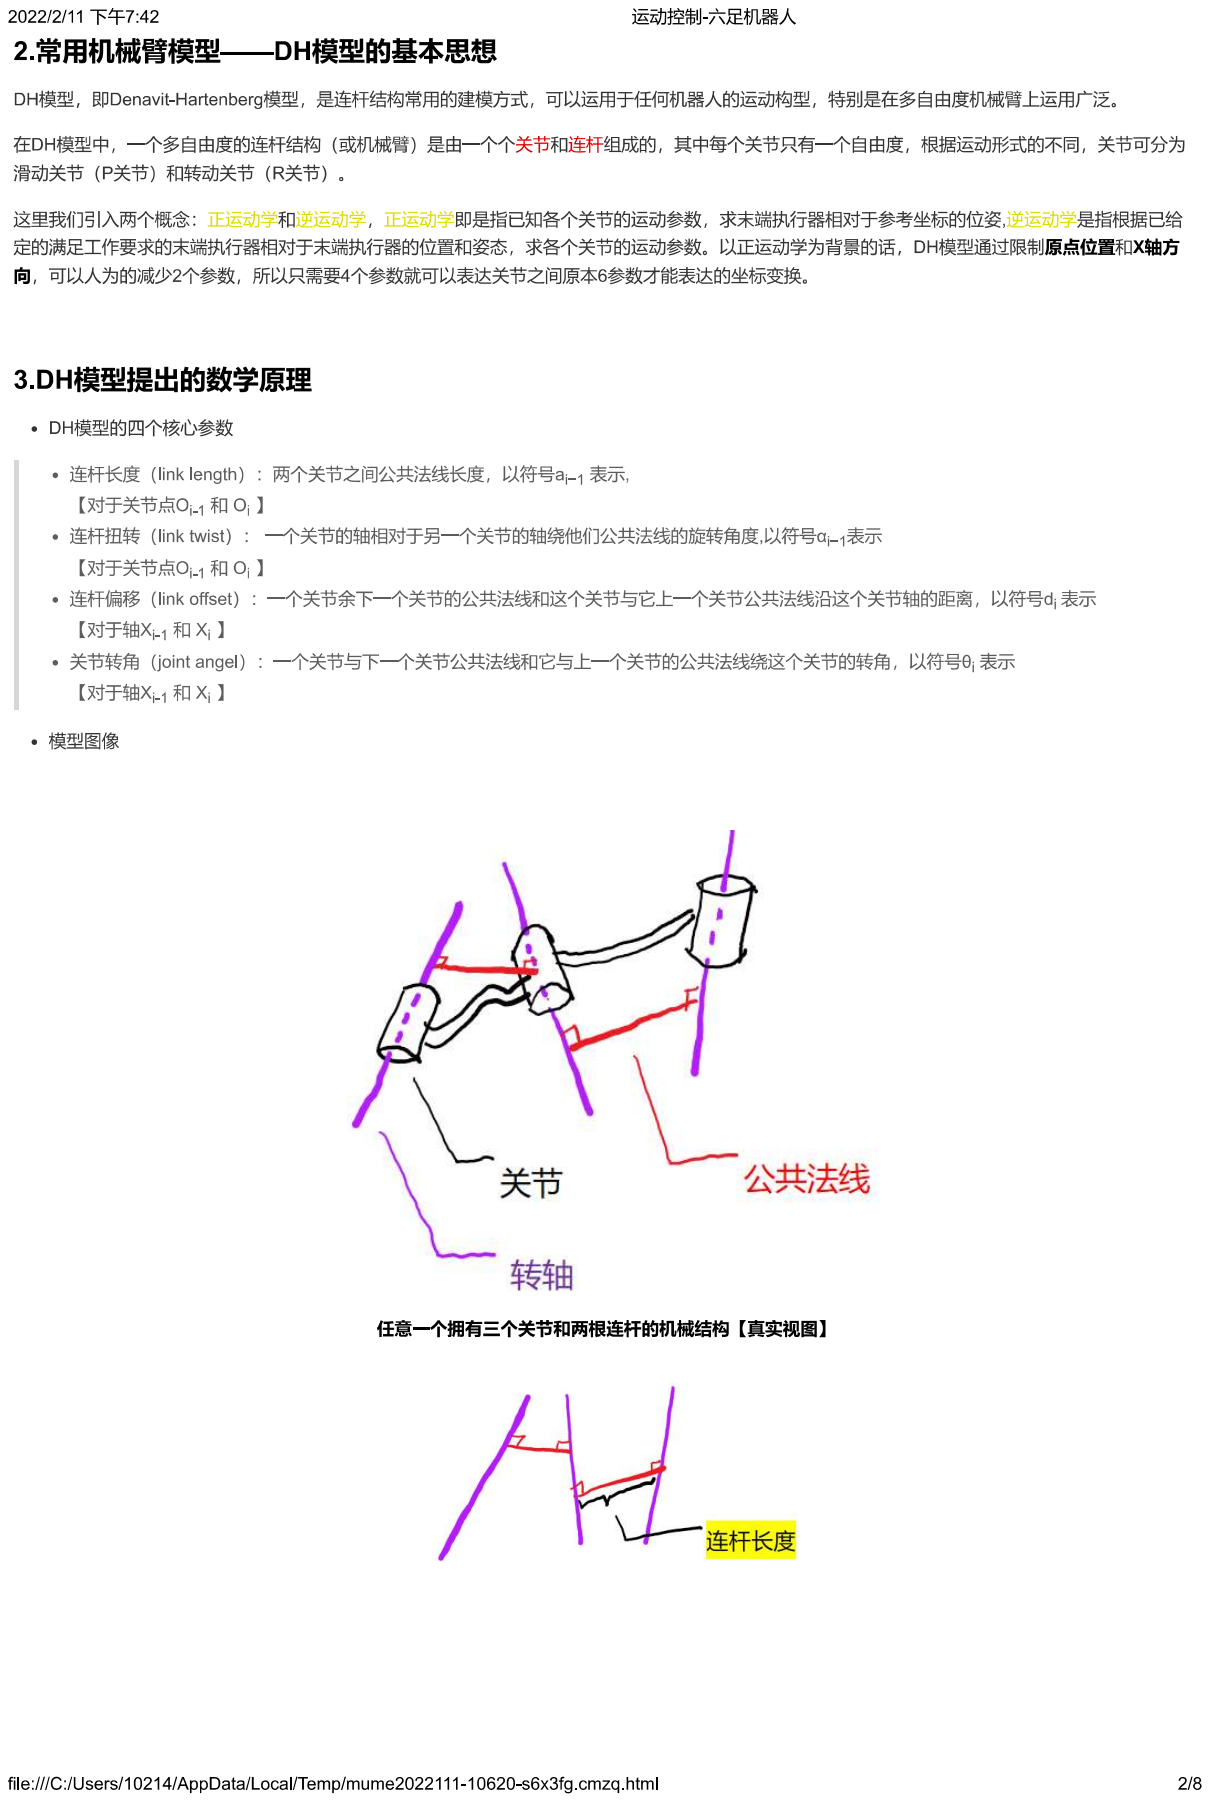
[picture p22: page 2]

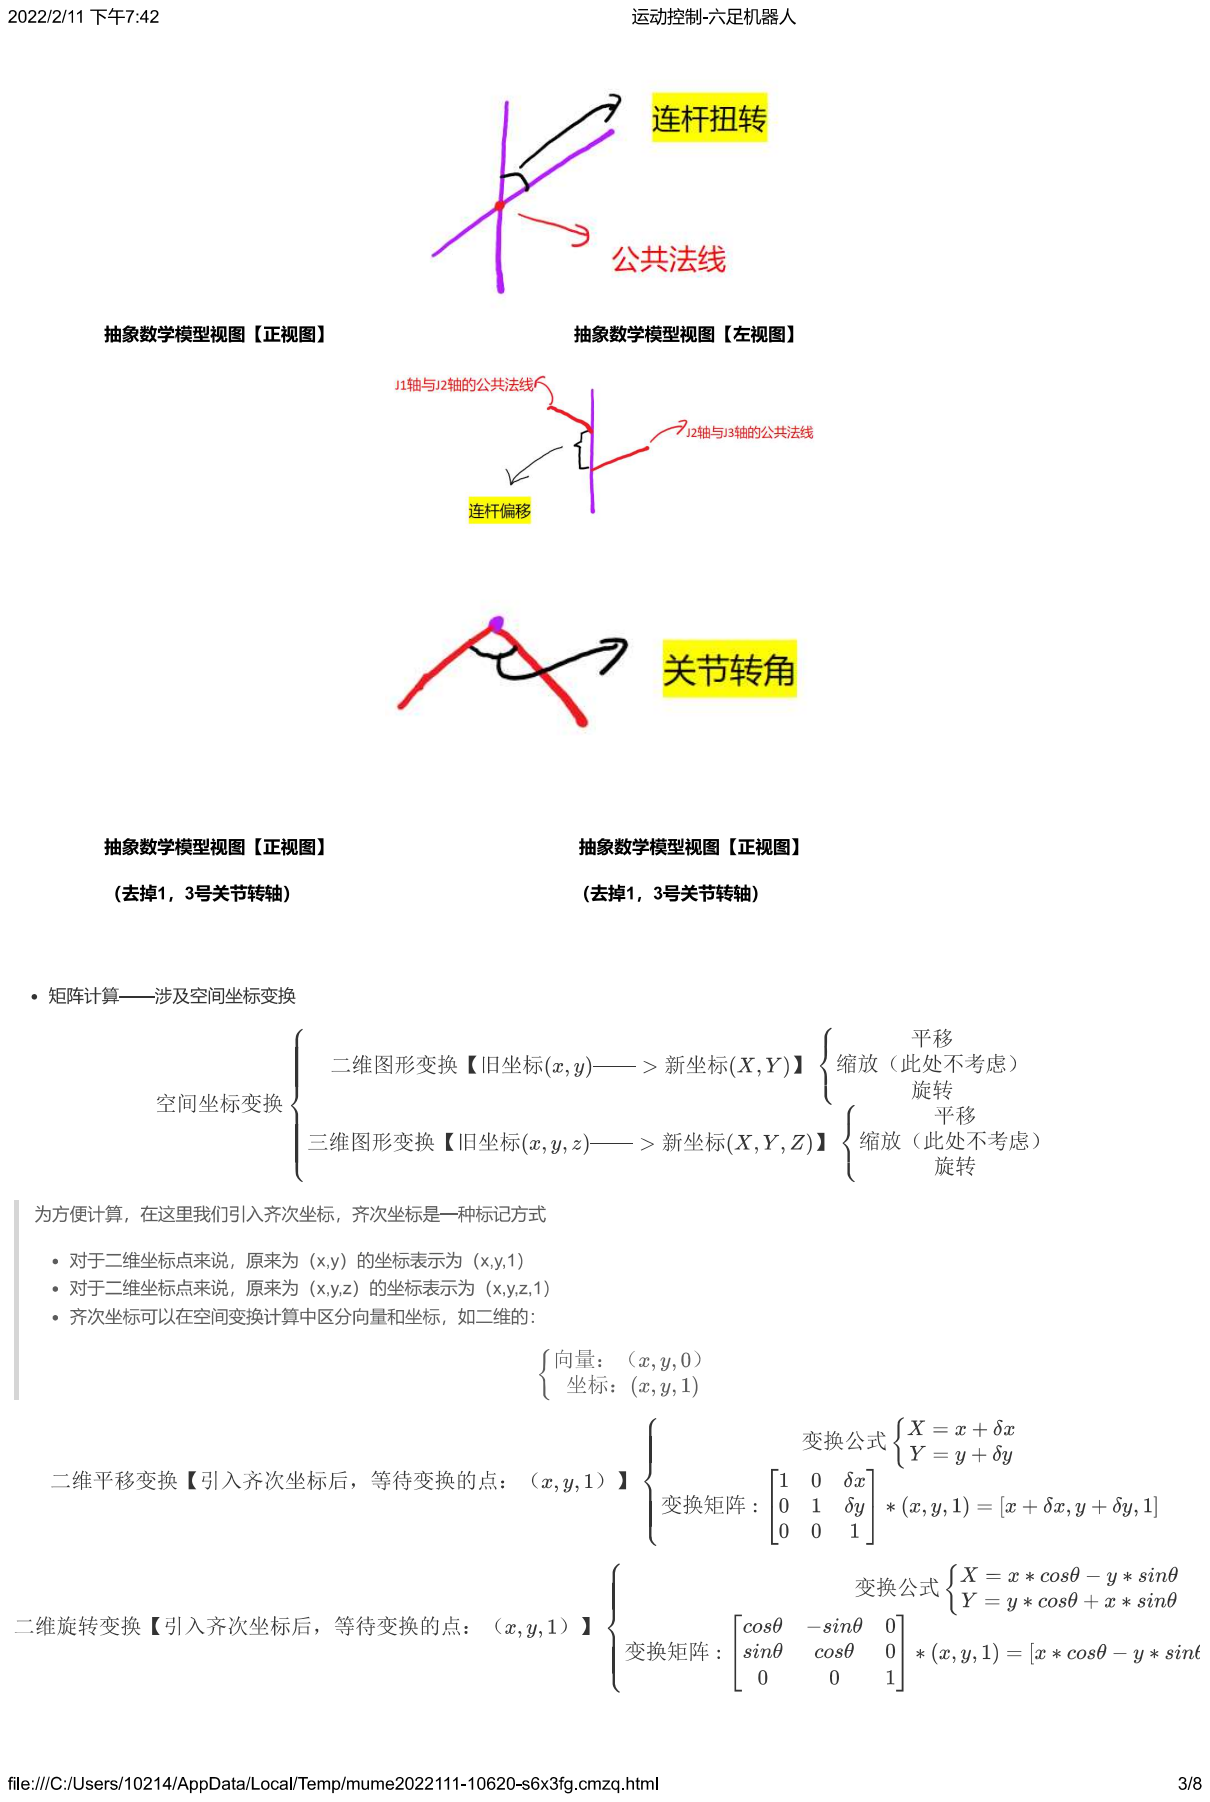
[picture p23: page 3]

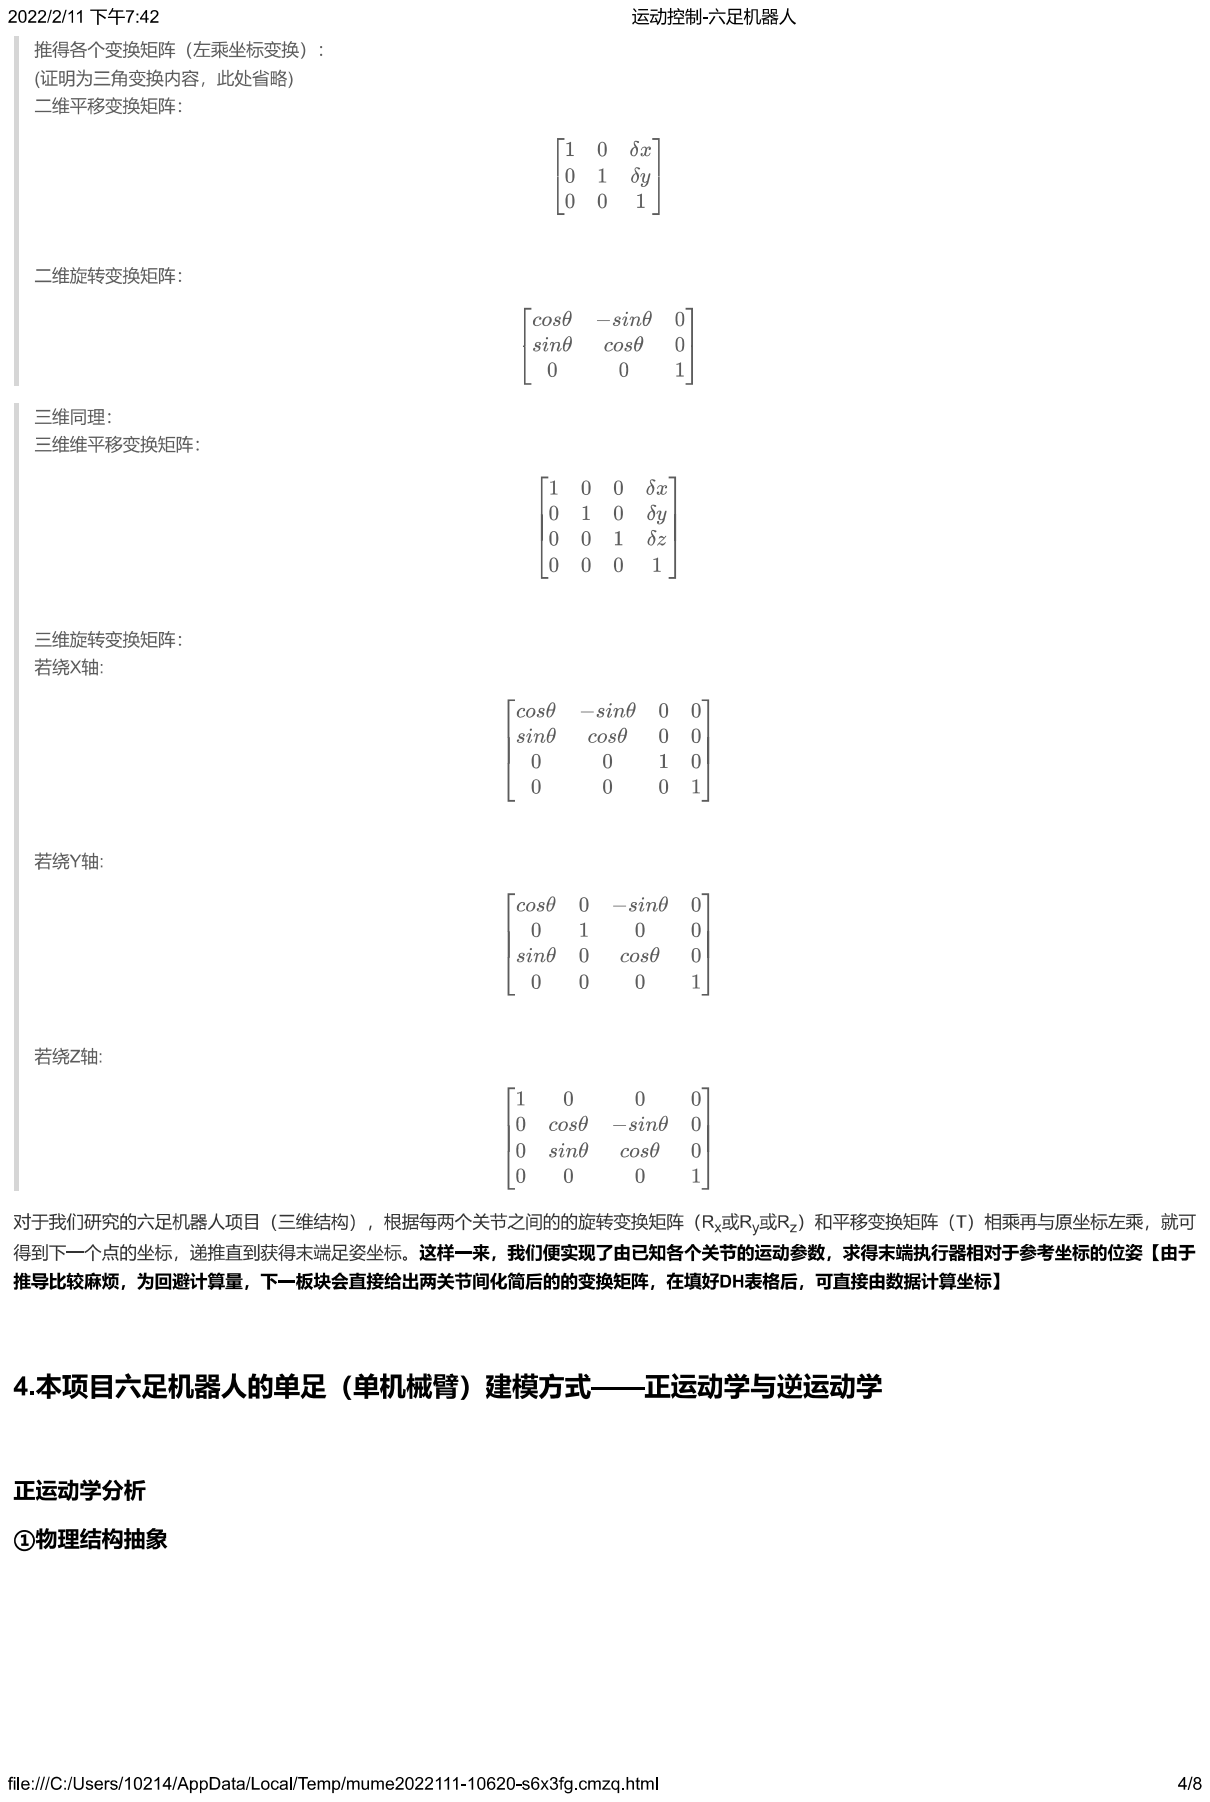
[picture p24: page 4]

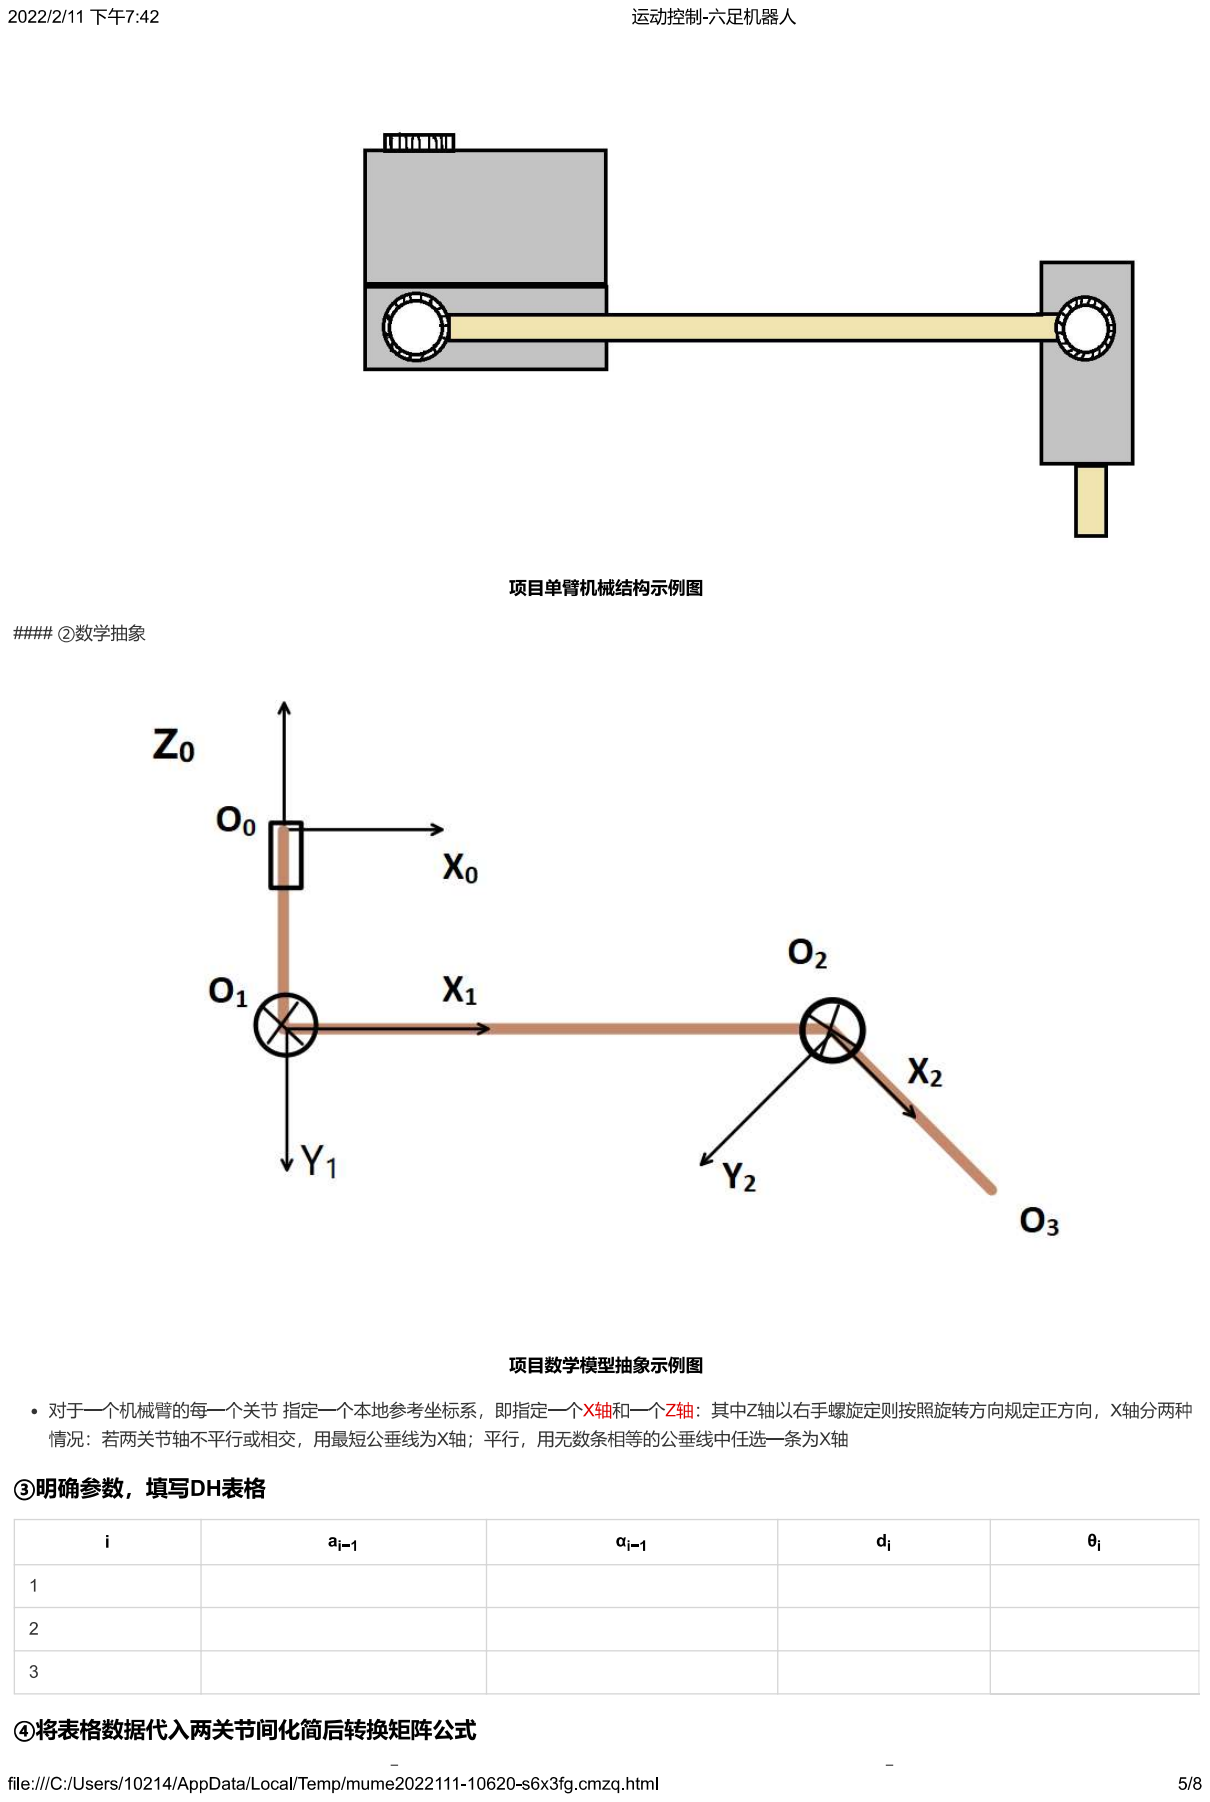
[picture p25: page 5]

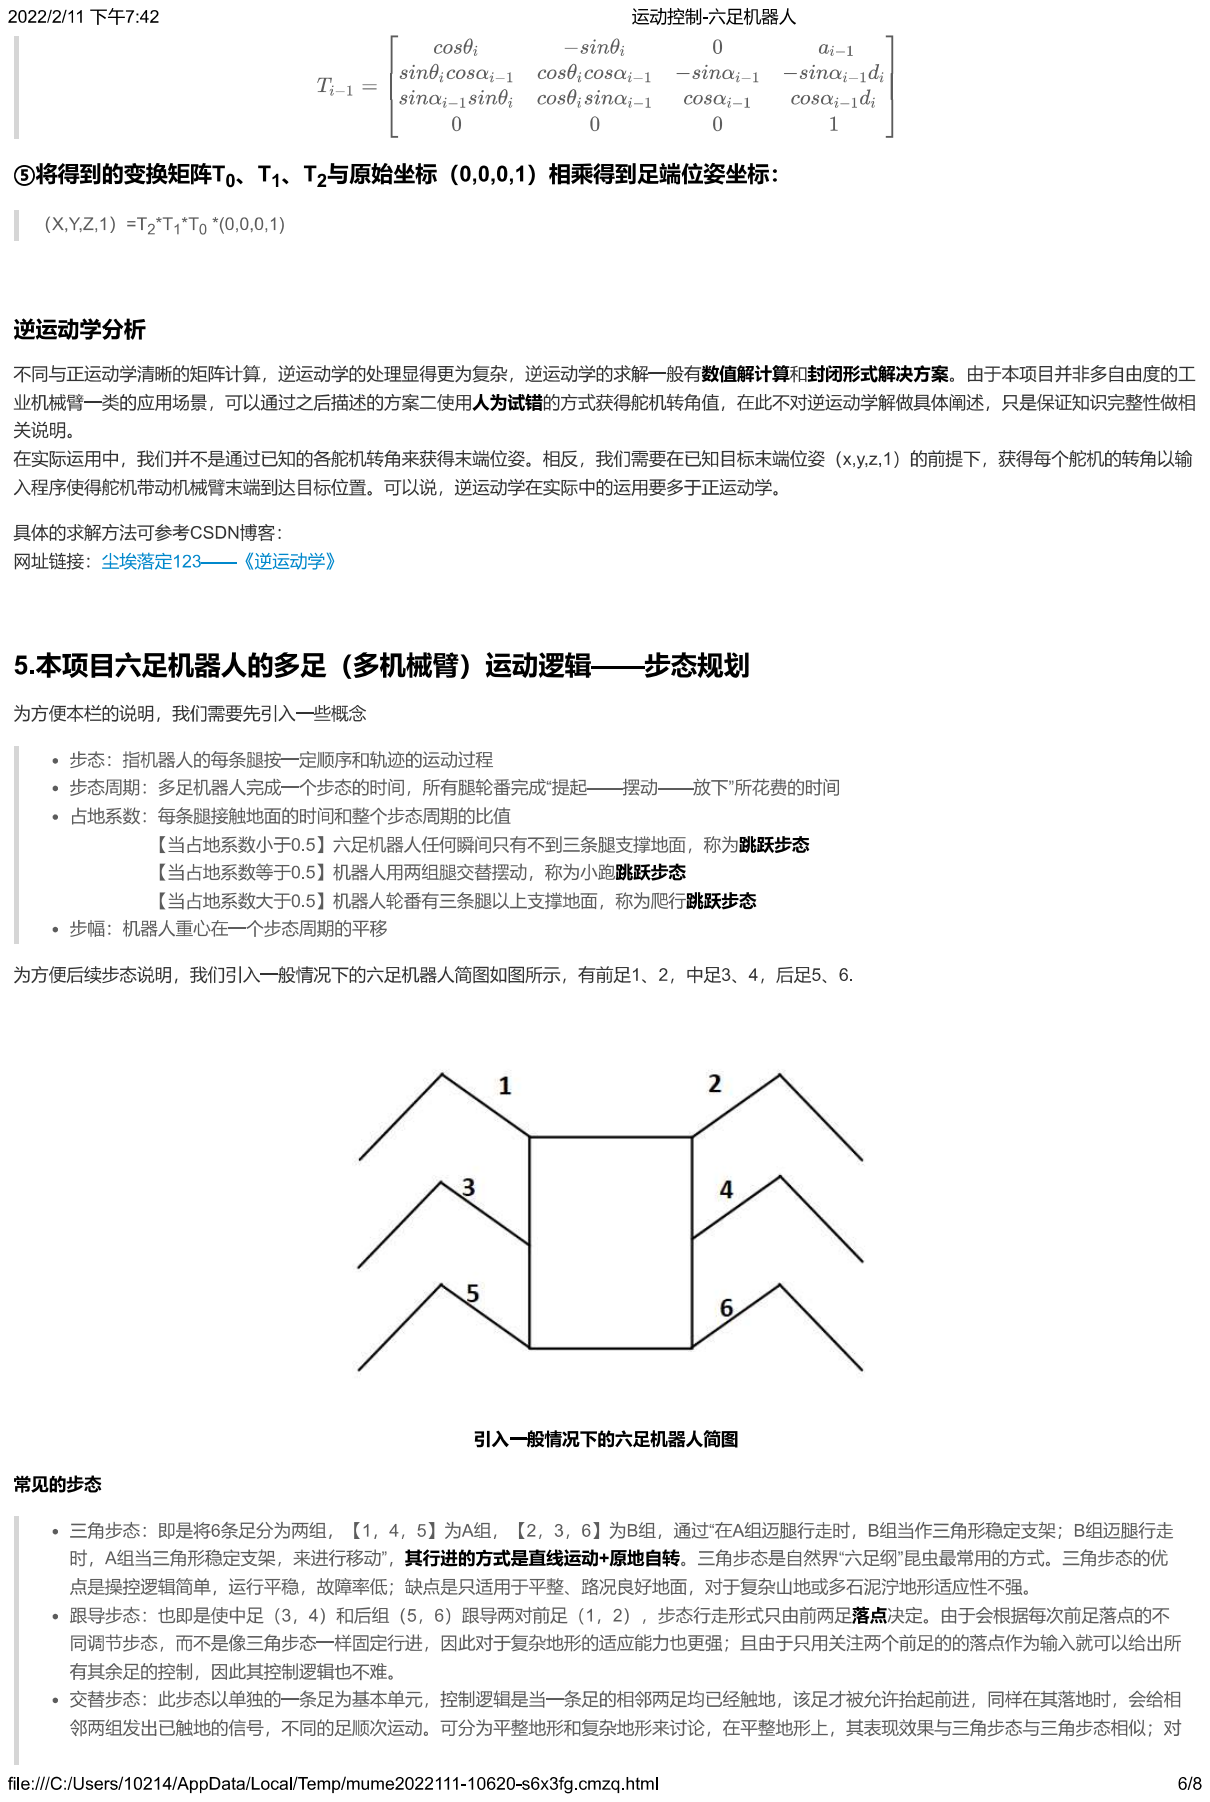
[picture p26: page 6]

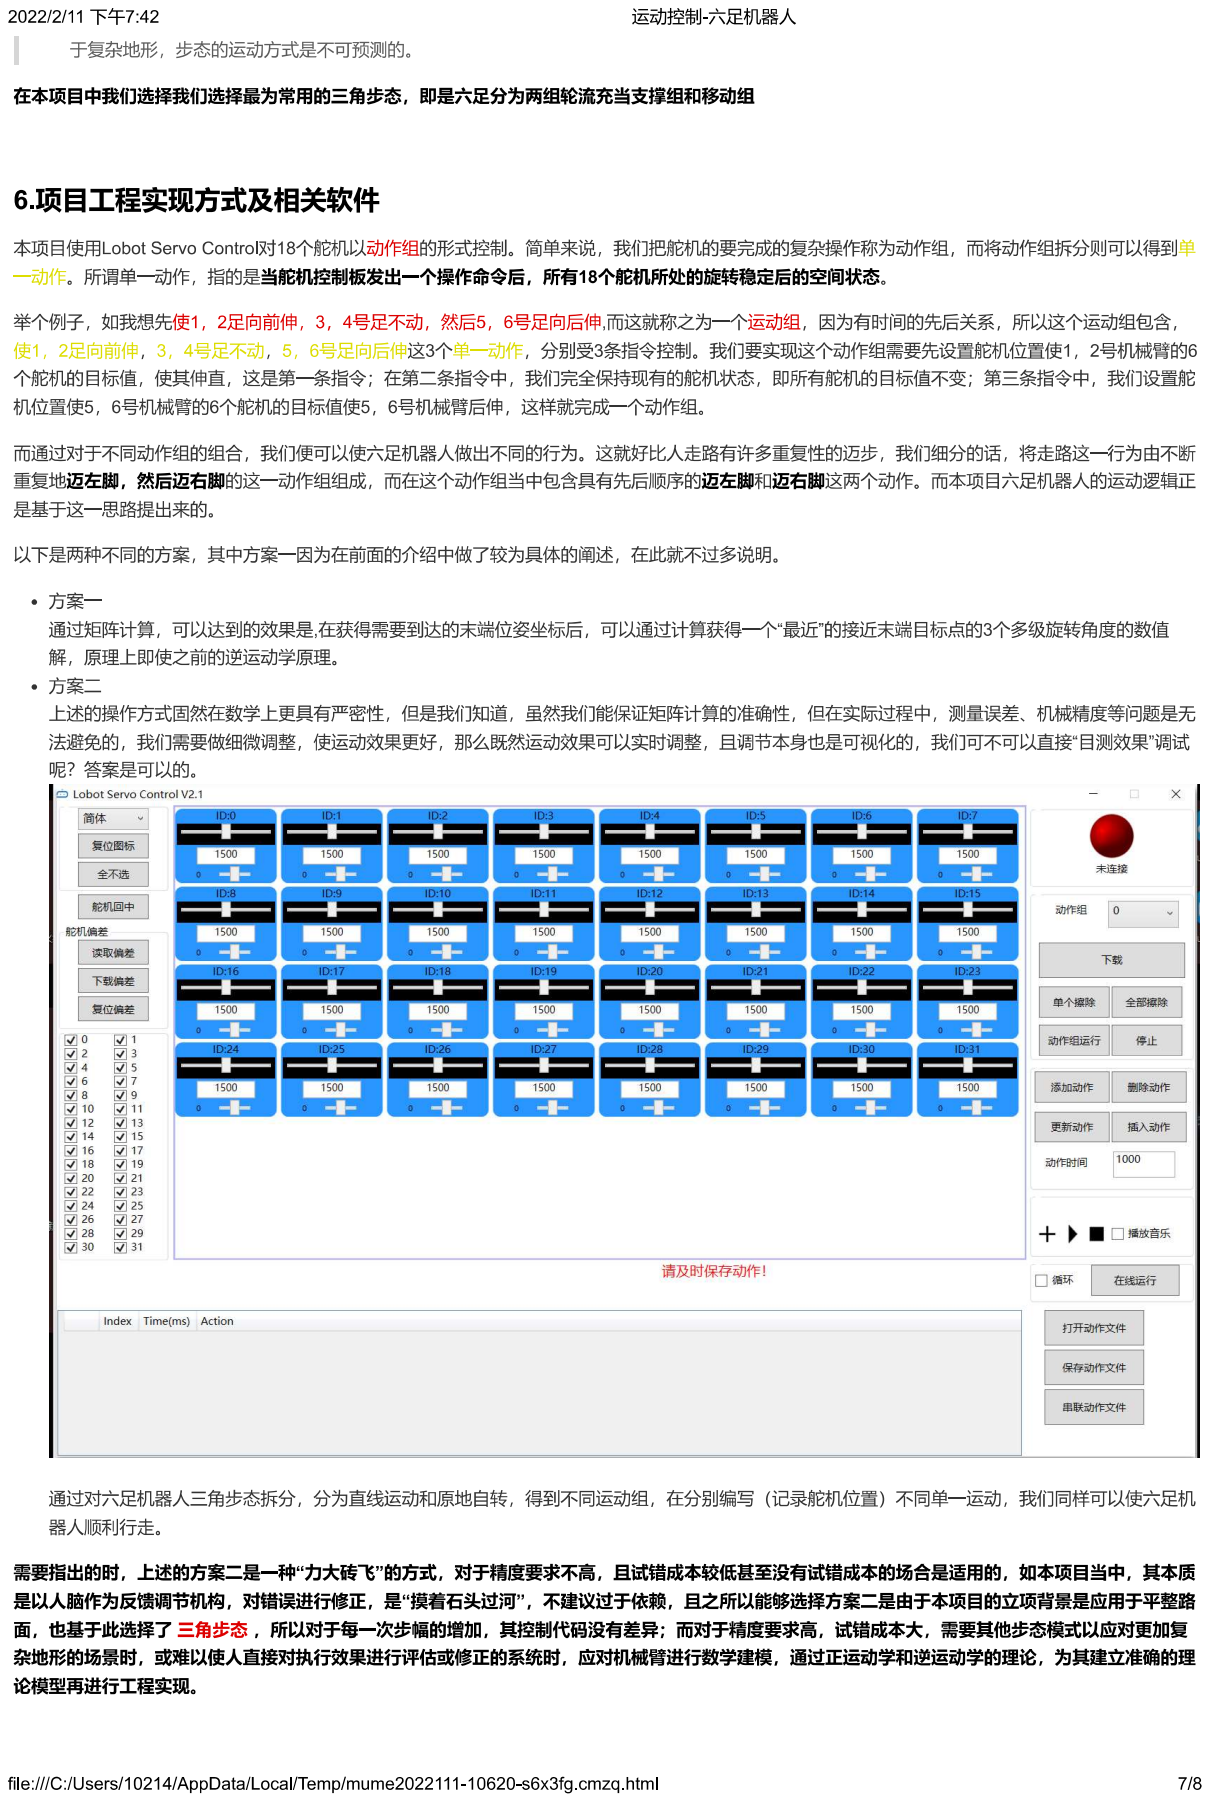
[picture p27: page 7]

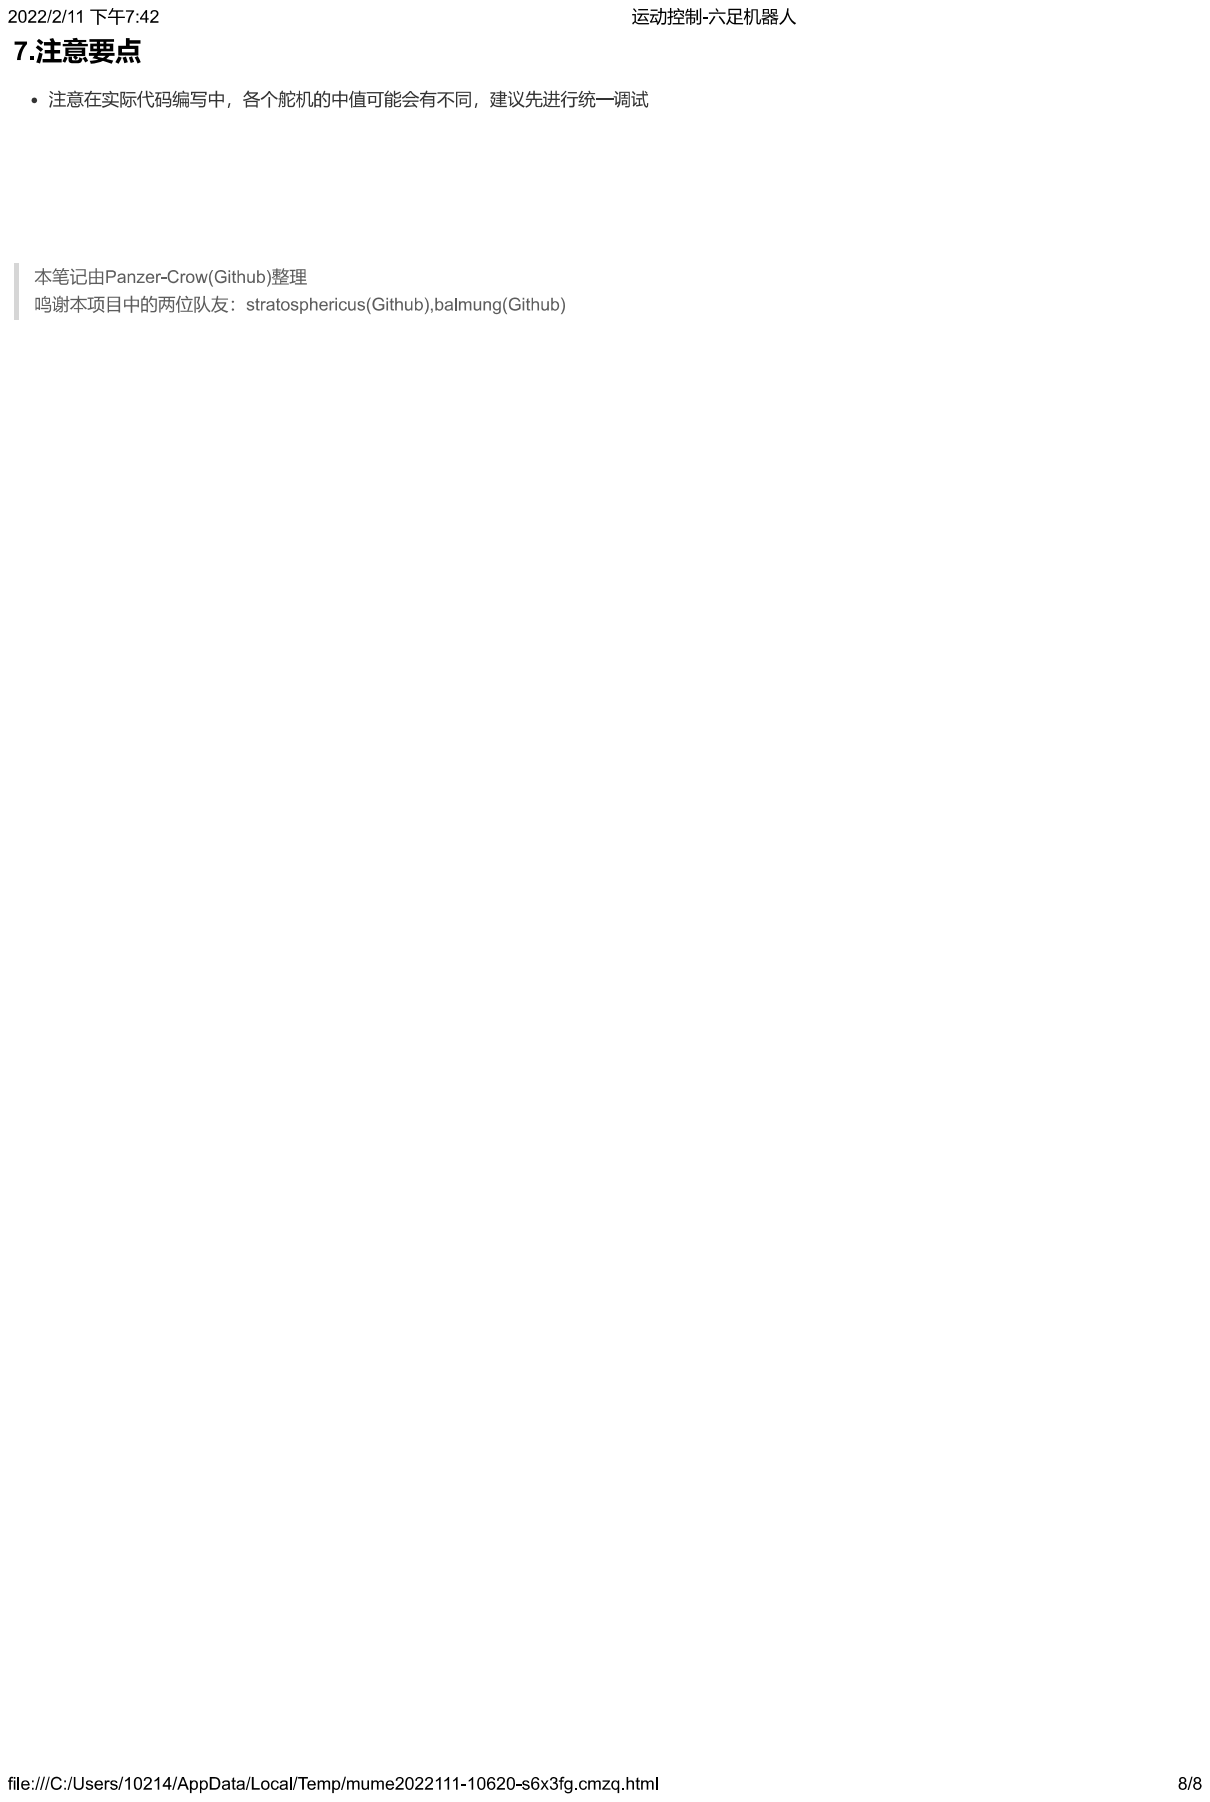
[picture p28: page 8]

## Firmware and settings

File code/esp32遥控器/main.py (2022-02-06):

from machine import I2C, Pin
from ssd1306 import SSD1306_I2C
import utime
import mpu6050
import network, time, _thread
import usocket as socket


#基本定义和初始化
i2c_mpu = I2C(scl=Pin(5), sda=Pin(4))
imu = mpu6050.accel(i2c_mpu)
i2c_oled = I2C(sda=Pin(13), scl=Pin(14)) 
oled = SSD1306_I2C(128, 64, i2c_oled, addr=0x3c) #前两个参数是分辨率，后两个是i2c地址

#水平校准常量
gyro_calib_Z = 1.28/4
gyro_calib_Y = 0.04/4
gyro_calib_X = -5.46/4
accel_calib_X = 0
accel_calib_Y = 0
accel_calib_Z = 0
earth_G = 11

# 响应头
responseHeaders = b'''
HTTP/1.1 200 OK
Content-Type: text/html
Connection: close

'''



def get_gyro_rad():
    """ 删除无关项，仅保留换算后的角加速度，并延迟100ms(没什么用，因为不计算yaw)
    """
    
    imu_dict_gyro = imu.get_values()
    del imu_dict_gyro['Tmp']
    del imu_dict_gyro['AcX']
    del imu_dict_gyro['AcY']
    del imu_dict_gyro['AcZ']
    imu_dict_gyro['GyX'] = imu_dict['GyX']*0.03051757812/4-gyro_calib_X
    imu_dict_gyro['GyY'] = imu_dict['GyY']*0.03051757812/4-gyro_calib_Y
    imu_dict_gyro['GyZ'] = imu_dict['GyZ']*0.03051757812/4-gyro_calib_Z
    utime.sleep_ms(100)
    return imu_dict_gyro

def get_tilt():
    """
    利用与重力夹角求得两个倾斜角，并延迟10ms,
    tilt_X, tilt_Y是cos值，正向正半轴低头，负向正半轴仰头。
    tilt_Z是绕z轴角速度
    """
    
    imu_dict_accel = imu.get_values()
    del imu_dict_accel['Tmp']
    del imu_dict_accel['GyX']
    del imu_dict_accel['GyY']
    #del imu_dict_accel['GyZ']
    imu_dict_accel['AcX'] = imu_dict_accel['AcX']*0.00059814453-accel_calib_X
    imu_dict_accel['AcY'] = imu_dict_accel['AcY']*0.00059814453-accel_calib_Y
    #imu_dict_accel['AcZ'] = imu_dict_accel['AcZ']*0.00059814453-accel_calib_Z
    imu_dict_accel['GyZ'] = imu_dict_accel['GyZ']*0.03051757812/4-gyro_calib_Z

    tilt_X = (imu_dict_accel['AcX']/earth_G)
    tilt_Y = (imu_dict_accel['AcY']/earth_G)
    tilt_Z = (imu_dict_accel['GyZ'])
    del imu_dict_accel['AcZ']
    tilt_angle = {"tilt_X": tilt_X, "tilt_Y": tilt_Y, "rot_Z": tilt_Z}
    utime.sleep_ms(10)
    return tilt_angle

def judge_instruct():
    """取最新的五个重力角余弦求平均,统计得到方向。X正为B，负为F。Y正为R，负为L. C是顺时针，A是逆时针。
    """
    
    avg_tilt_X = 0
    samp_X = 1
    while samp_X <= 5:
        avg_tilt_X = get_tilt()["tilt_X"] + avg_tilt_X
        samp_X = samp_X + 1
    avg_tilt_X = avg_tilt_X/5
    
    avg_tilt_Y = 0
    samp_Y = 1
    while samp_Y <= 5:
        avg_tilt_Y = get_tilt()["tilt_Y"] + avg_tilt_Y
        samp_Y = samp_Y + 1
    avg_tilt_Y = avg_tilt_Y/5

    avg_tilt_Z = 0
    samp_Z = 1
    while samp_Z <= 5:
        avg_tilt_Z = get_tilt()["rot_Z"] + avg_tilt_Z
        samp_Z = samp_Z + 1
    avg_tilt_Z = avg_tilt_Z/5

    #等级判断
    instruction_X = "X"
    if avg_tilt_X <= 0.1 and avg_tilt_X > 0:
        instruction_X = "F0"
    elif avg_tilt_X <= 0.2 and avg_tilt_X > 0.1:
        instruction_X = "F1"
    elif avg_tilt_X <= 0.3 and avg_tilt_X > 0.2:
        instruction_X = "F2"
    elif avg_tilt_X <= 0.4 and avg_tilt_X > 0.3:
        instruction_X = "F3"
    elif avg_tilt_X <= 0.5 and avg_tilt_X > 0.4:
        instruction_X = "F4"
    elif avg_tilt_X <= 0.6 and avg_tilt_X > 0.5:
        instruction_X = "F5"
    elif avg_tilt_X <= 0.7 and avg_tilt_X > 0.6:
        instruction_X = "F6"
    elif avg_tilt_X <= 0.8 and avg_tilt_X > 0.7:
        instruction_X = "F7"
    elif avg_tilt_X <= 0.9 and avg_tilt_X > 0.8:
        instruction_X =  "F8"
    elif avg_tilt_X <= 1 and avg_tilt_X > 0.9:
        instruction_X =  "F9"
    elif avg_tilt_X > 1:
        instruction_X =  "F10"    
    elif avg_tilt_X >= -0.1 and avg_tilt_X < 0:
        instruction_X =  "B0"
    elif avg_tilt_X >= -0.2 and avg_tilt_X < -0.1:
        instruction_X =  "B1"
    elif avg_tilt_X >= -0.3 and avg_tilt_X < -0.2:
        instruction_X =  "B2"
    elif avg_tilt_X >= -0.4 and avg_tilt_X < -0.3:
        instruction_X =  "B3"
    elif avg_tilt_X >= -0.5 and avg_tilt_X < -0.4:
        instruction_X =  "B4"
    elif avg_tilt_X >= -0.6 and avg_tilt_X < -0.5:
        instruction_X =  "B5"
    elif avg_tilt_X >= -0.7 and avg_tilt_X < -0.6:
        instruction_X =  "B6"
    elif avg_tilt_X >= -0.8 and avg_tilt_X < -0.7:
        instruction_X =  "B7"
    elif avg_tilt_X >= -0.9 and avg_tilt_X < -0.8:
        instruction_X =  "B8"
    elif avg_tilt_X >= -1 and avg_tilt_X < -0.9:
        instruction_X =  "B9"
    elif avg_tilt_X < -1:
        instruction_X =  "B10"
    else:
        instruction_X =  "X"
    

    #等级判断
    instruction_Y = "Y"
    if avg_tilt_Y <= 0.1 and avg_tilt_Y > 0:
        instruction_Y =  "L0"
    elif avg_tilt_Y <= 0.2 and avg_tilt_Y > 0.1:
        instruction_Y =  "L1"
    elif avg_tilt_Y <= 0.3 and avg_tilt_Y > 0.2:
        instruction_Y =  "L2"
    elif avg_tilt_Y <= 0.4 and avg_tilt_Y > 0.3:
        instruction_Y =  "L3"
    elif avg_tilt_Y <= 0.5 and avg_tilt_Y > 0.4:
        instruction_Y =  "L4"
    elif avg_tilt_Y <= 0.6 and avg_tilt_Y > 0.5:
        instruction_Y =  "L5"
    elif avg_tilt_Y <= 0.7 and avg_tilt_Y > 0.6:
        instruction_Y =  "L6"
    elif avg_tilt_Y <= 0.8 and avg_tilt_Y > 0.7:
        instruction_Y =  "L7"
    elif avg_tilt_Y <= 0.9 and avg_tilt_Y > 0.8:
        instruction_Y =  "L8"
    elif avg_tilt_Y <= 1 and avg_tilt_Y > 0.9:
        instruction_Y =  "L9"
    elif avg_tilt_Y > 1:
        instruction_Y =  "L10"    
    elif avg_tilt_Y >= -0.1 and avg_tilt_Y < 0:
        instruction_Y =  "R0"
    elif avg_tilt_Y >= -0.2 and avg_tilt_Y < -0.1:
        instruction_Y =  "R1"
    elif avg_tilt_Y >= -0.3 and avg_tilt_Y < -0.2:
        instruction_Y =  "R2"
    elif avg_tilt_Y >= -0.4 and avg_tilt_Y < -0.3:
        instruction_Y =  "R3"
    elif avg_tilt_Y >= -0.5 and avg_tilt_Y < -0.4:
        instruction_Y =  "R4"
    elif avg_tilt_Y >= -0.6 and avg_tilt_Y < -0.5:
        instruction_Y =  "R5"
    elif avg_tilt_Y >= -0.7 and avg_tilt_Y < -0.6:
        instruction_Y =  "R6"
    elif avg_tilt_Y >= -0.8 and avg_tilt_Y < -0.7:
        instruction_Y =  "R7"
    elif avg_tilt_Y >= -0.9 and avg_tilt_Y < -0.8:
        instruction_Y =  "R8"
    elif avg_tilt_Y >= -1 and avg_tilt_Y < -0.9:
        instruction_Y =  "R9"
    elif avg_tilt_Y < -1:
        instruction_Y =  "R10"     
    else:
        instruction_Y =  "Y"
    
    #等级判断
    instruction_Z = "Z"
    if avg_tilt_Z <= 25 and avg_tilt_Z > 0:
        instruction_Z =  "A0"
    elif avg_tilt_Z <= 50 and avg_tilt_Z > 25:
        instruction_Z =  "A1"
    elif avg_tilt_Z <= 75 and avg_tilt_Z > 50:
        instruction_Z =  "A2"
    elif avg_tilt_Z <= 100 and avg_tilt_Z > 75:
        instruction_Z =  "A3"
    elif avg_tilt_Z <= 125 and avg_tilt_Z > 100:
        instruction_Z =  "A4"
    elif avg_tilt_Z <= 150 and avg_tilt_Z > 125:
        instruction_Z =  "A5"
    elif avg_tilt_Z <= 175 and avg_tilt_Z > 150:
        instruction_Z =  "A6"
    elif avg_tilt_Z <= 200 and avg_tilt_Z > 175:
        instruction_Z =  "A7"
    elif avg_tilt_Z <= 225 and avg_tilt_Z > 200:
        instruction_Z =  "A8"
    elif avg_tilt_Z <= 256 and avg_tilt_Z > 225:
        instruction_Z =  "A9"
    elif avg_tilt_Z >= -25 and avg_tilt_Z < 0:
        instruction_Z =  "C0"
    elif avg_tilt_Z >= -50 and avg_tilt_Z < -25:
        instruction_Z =  "C1"
    elif avg_tilt_Z >= -75 and avg_tilt_Z < -50:
        instruction_Z =  "C2"
    elif avg_tilt_Z >= -100 and avg_tilt_Z < -75:
        instruction_Z =  "C3"
    elif avg_tilt_Z >= -125 and avg_tilt_Z < -100:
        instruction_Z =  "C4"
    elif avg_tilt_Z >= -150 and avg_tilt_Z < -125:
        instruction_Z =  "C5"
    elif avg_tilt_Z >= -175 and avg_tilt_Z < -150:
        instruction_Z =  "C6"
    elif avg_tilt_Z >= -200 and avg_tilt_Z < -175:
        instruction_Z =  "C7"
    elif avg_tilt_Z >= -225 and avg_tilt_Z < -200:
        instruction_Z =  "C8"
    elif avg_tilt_Z >= -256 and avg_tilt_Z < -225:
        instruction_Z =  "C9" 
    else:
        instruction_Z =  "C"

    
    
    instructions = {"instruct_X": instruction_X, "instruct_Y": instruction_Y, "instruct_Z": instruction_Z}
    return instructions

def WIFI_Connect():
    """连接wifi并且打印信息
    """

    wlan = network.WLAN(network.STA_IF) #STA模式
    wlan.active(True)                   #激活接口
    start_time=time.time()              #记录时间做超时判断

    if not wlan.isconnected():
        print('connecting to network...')
        wlan.connect('test', '88888888') #输入WIFI的SSID和密码

        while not wlan.isconnected():
            #15S超时判断
            if time.time()-start_time > 15 :
                print('WIFI Connected Timeout!')
                break

    if wlan.isconnected():
        print('network information:', wlan.ifconfig())

def oled_display(ur_command, wifi_config):
    """ 分别打印三行信息：指令、wifi地址、spiderbot
    """

    first_line = "Command: " + ur_command['instruct_X'] + ur_command['instruct_Y'] + ur_command['instruct_Z']
    second_line = "Address: " + wifi_config[0]
    third_line = "SpiderBot"
    #在指定像素坐标分别写入三行后执行显示
    oled.text(first_line, 0,  0)      
    oled.text(second_line,  0, 20)      
    oled.text(third_line,  0, 40)     
    oled.show()


def webserver():
    """实现一个简单的webserver用来接受get请求，返回和oled的第一行同样显示内容
    """
    
    s = socket.socket()
    s.setsockopt(socket.SOL_SOCKET, socket.SO_REUSEADDR, 1) # (重要)设置端口释放后立即就可以被再次使用
    s.bind(socket.getaddrinfo("0.0.0.0", 80)[0][-1])  # 绑定地址
    s.listen(5)  # 开启监听（最大连接数5）
    while True:
        client_sock, client_addr = s.accept()  # 接收来自客户端的请求与客户端地址

        while True:
            h = client_sock.readline()
            if h == b'' or h == b'\r\n':
                break
        ur_command = judge_instruct()
        client_sock.write(responseHeaders) # 向客户端发送响应头
        client_sock.write(ur_command['instruct_X'] + ur_command['instruct_Y'] + ur_command['instruct_Z']) # 向客户端发送网页内容
        client_sock.close()

def main():
    """主循环
    """
    while 1:
        #print(judge_instruct())
        ur_command = judge_instruct()
        oled_display(ur_command, wifi_config) #让oled显示内容
        


WIFI_Connect()

wlan = network.WLAN(network.STA_IF)    
wifi_config = wlan.ifconfig()


#多线程
_thread.start_new_thread(main, ())
_thread.start_new_thread(webserver, ())


#读入指令，调用显示函数，显示当前指令和wifi状态
#ur_command = judge_instruct()
#oled_display(ur_command, wifi_config)

#测试打印
#print(wifi_config)
#print(judge_instruct())
    

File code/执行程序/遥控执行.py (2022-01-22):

import socket
import time

def connect():
    # HOST = 'localhost'
    HOST = 'xxx.xx.xx.xxx'  #公网IP
    PORT = 1178
    sock = socket.socket(socket.AF_INET, socket.SOCK_STREAM)
    sock.setsockopt(socket.SOL_SOCKET,socket.SO_REUSEADDR,1)
    sock.connect((HOST, PORT))
    return sock
def test(status):
    status = int(status)
    if status == 0:
        print("停止")
    if status == 1:
        print("前进")
    if status == 2:
        print("前右")
    if status == 3:
        print("右转")
    if status == 4:
        print("右后")
    if status == 5:
        print("后退")
    if status == 6:
        print("左后")
    if status == 7:
        print("左转")
    if status == 8:
        print("前左")
     
while True:
    sock = connect()
    status = sock.recv(1).decode()
    test(status)
    sock.close()
